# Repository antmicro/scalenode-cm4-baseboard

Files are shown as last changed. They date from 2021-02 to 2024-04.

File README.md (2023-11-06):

# Scalenode CM4 Baseboard

Copyright (c) 2020-2023 [Antmicro](https://www.antmicro.com)



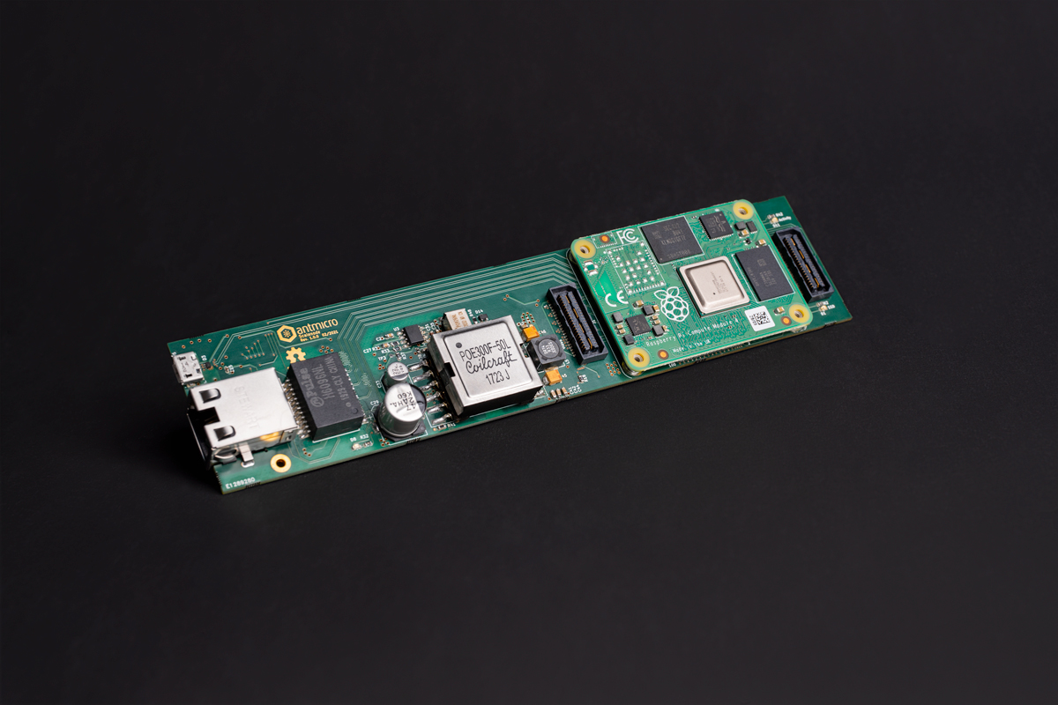
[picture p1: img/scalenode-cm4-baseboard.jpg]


## Overview

This project contains the PCB design files for a baseboard supporting System on Modules with pinout compatible with Raspberry Pi Compute Module 4 (CM4).
The baseboard has been optimized for 19-inch rack mount installations for distributed multi-node computing systems.

## Project structure

The main directory contains KiCad PCB project files, a [LICENSE](LICENSE), and a README.
The remaining files are stored in the following directories:

* `lib` - contains the KiCad component libraries
* `doc` - contains generated schematics and other documentation
* `img` - contains graphics for this README
* `assets` - contains visual assets for showcasing this design on [Open Hardware Portal](https://openhardware.antmicro.com)

## Key features

* Supports Raspberry Pi CM4
* Gigabit Ethernet with integrated PoE circuitry
* On-board M.2 (key-M) slot supporting NVMe SSDs 
* Slim PCB outline for 1U chassis
* Expansion connector for peripherals connected over USB
* Expansion connector for HDMI adapters

## Block diagram

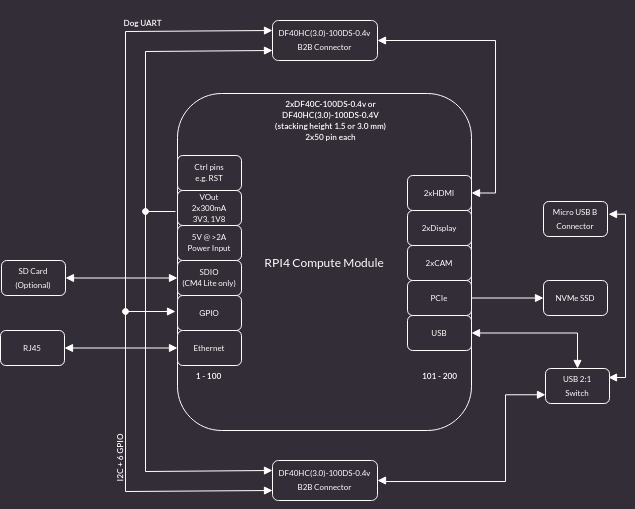
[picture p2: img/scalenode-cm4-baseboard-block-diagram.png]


## License

This project is published under the [Apache-2.0](LICENSE) license.

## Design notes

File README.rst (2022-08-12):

=======================
Scalenode CM4 Baseboard
=======================

Copyright (c) 2020-2021 `Antmicro <https://www.antmicro.com>`_



Overview
========

This repository contains the PCB design files for a baseboard supporting System on Modules with pinout compatible with Raspberry Pi Compute Module 4 (CM4).
The baseboard has been optimized for 19-inch rack mount installations for distributed multi-node computing systems.

Key features
============

* Supports Raspberry Pi CM4
* Gigabit Ethernet with integrated PoE circuitry
* On-board M.2 (key-M) slot supporting NVMe SSDs 
* Slim PCB outline for 1U chassis
* Expansion connector for peripherals connected over USB
* Expansion connector for HDMI adapters

Board layout and dimensions
===========================

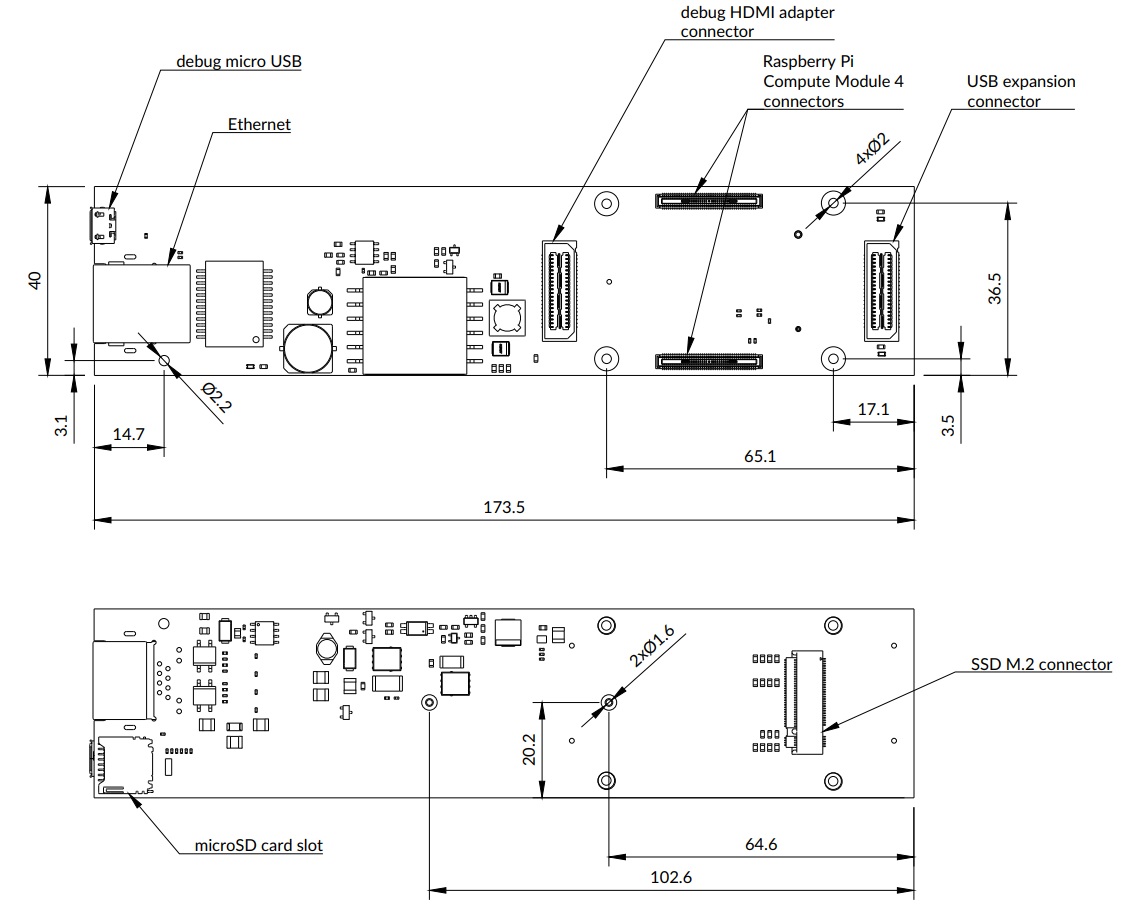
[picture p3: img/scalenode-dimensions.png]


License
=======

`Apache-2.0 <LICENSE>`_

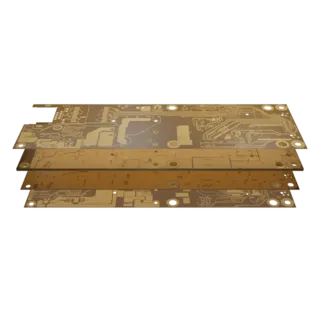
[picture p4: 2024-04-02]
assets/previews/layer1_thumbnail.webp

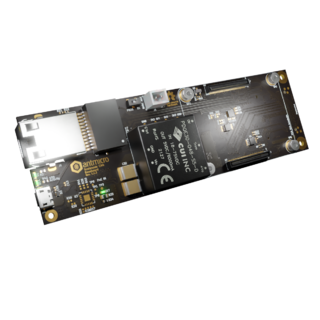
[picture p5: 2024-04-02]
assets/previews/leftT_thumbnail.png

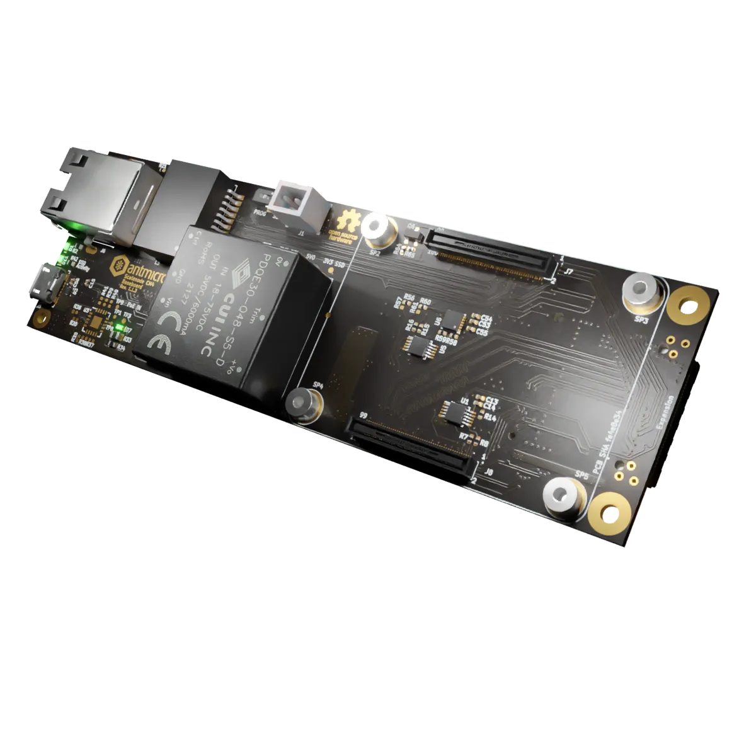
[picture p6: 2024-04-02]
assets/previews/rightT.webp

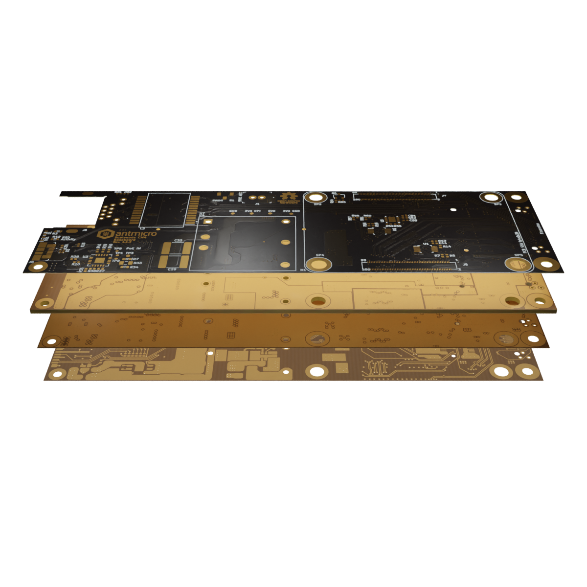
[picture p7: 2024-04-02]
assets/previews/stackup.png

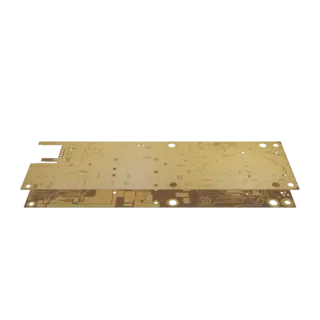
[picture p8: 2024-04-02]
assets/previews/layer3_thumbnail.webp

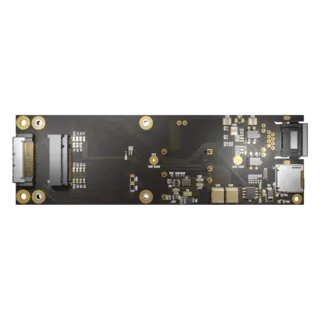
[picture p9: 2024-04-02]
assets/previews/orthoB_thumbnail.webp

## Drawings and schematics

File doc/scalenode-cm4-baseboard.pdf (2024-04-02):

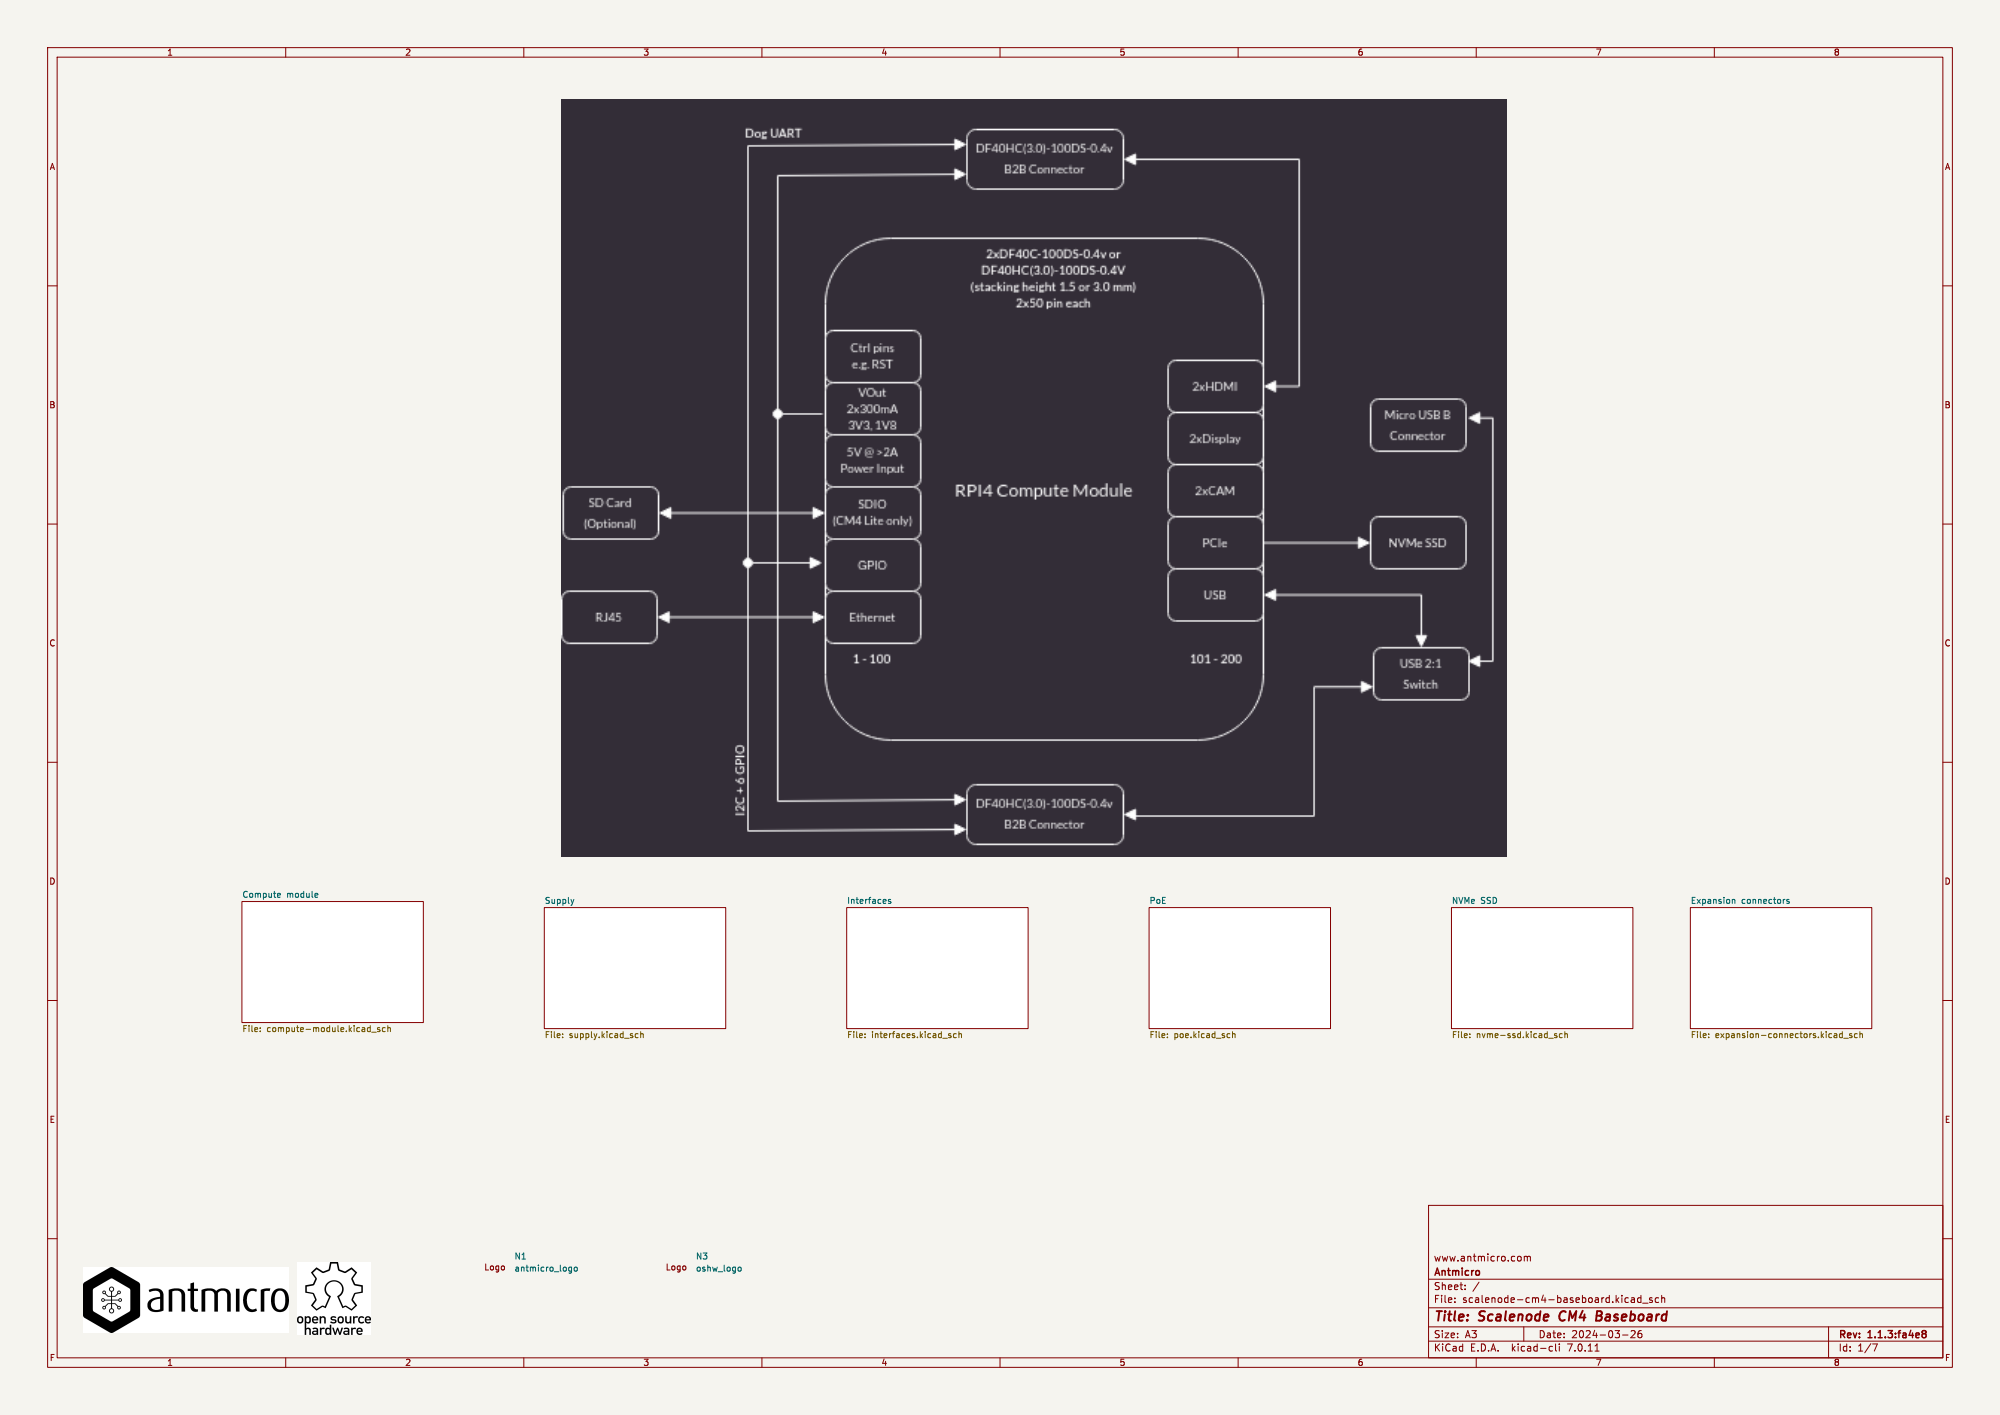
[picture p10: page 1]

File: scalenode-cm4-baseboard.kicad_sch Sheet: / Antmicro www.antmicro.com

Id: 1/7 Title: Scalenode CM4 Baseboard

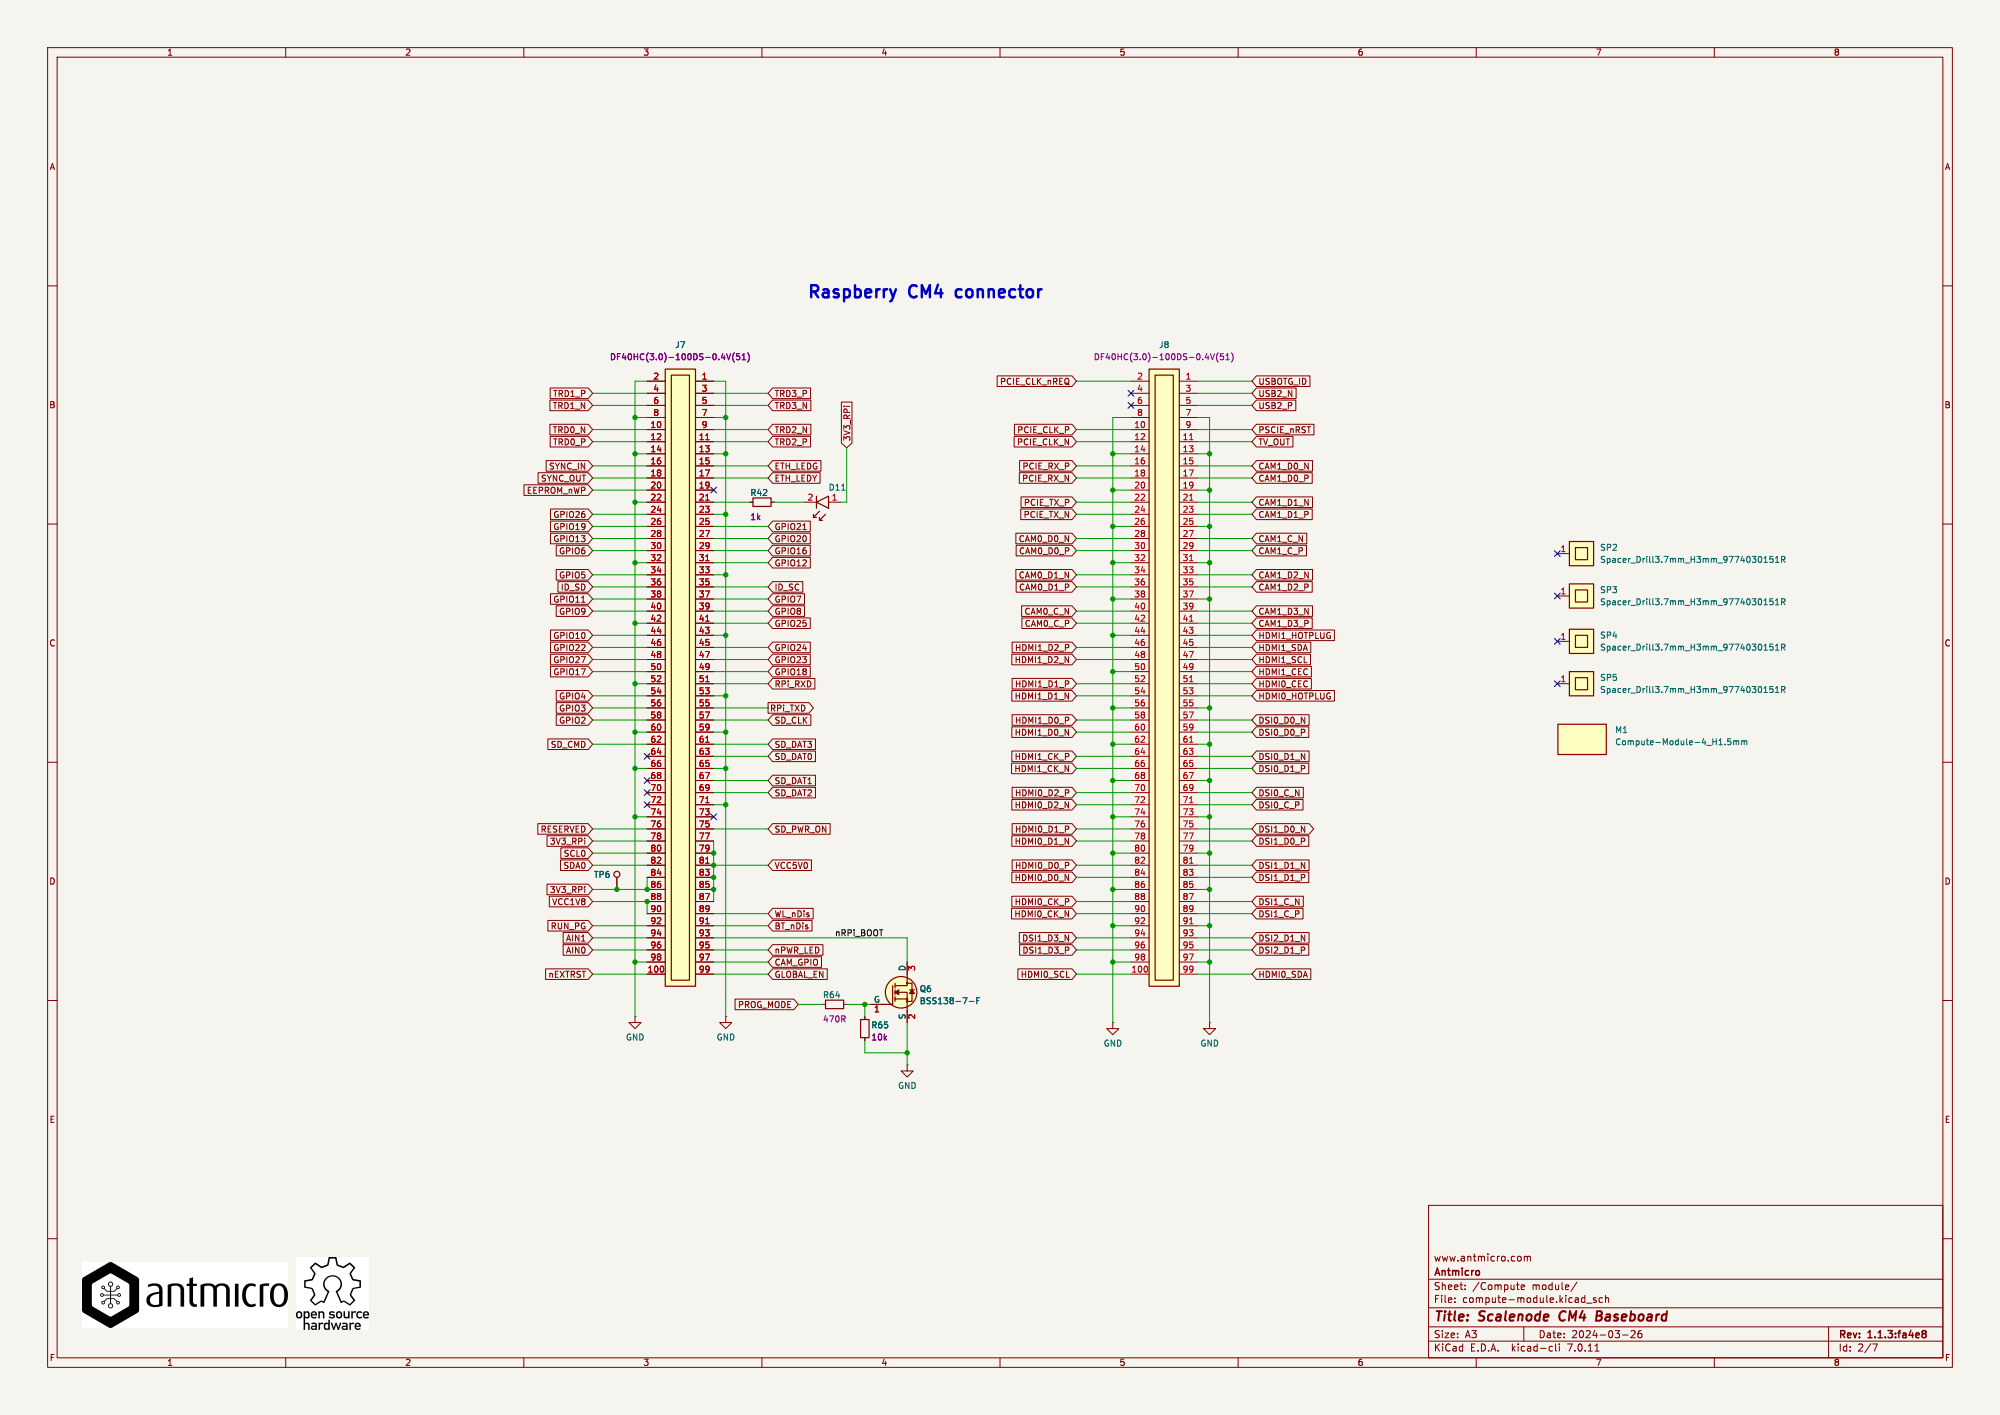
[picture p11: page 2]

Id: 2/7 Title: Scalenode CM4 Baseboard

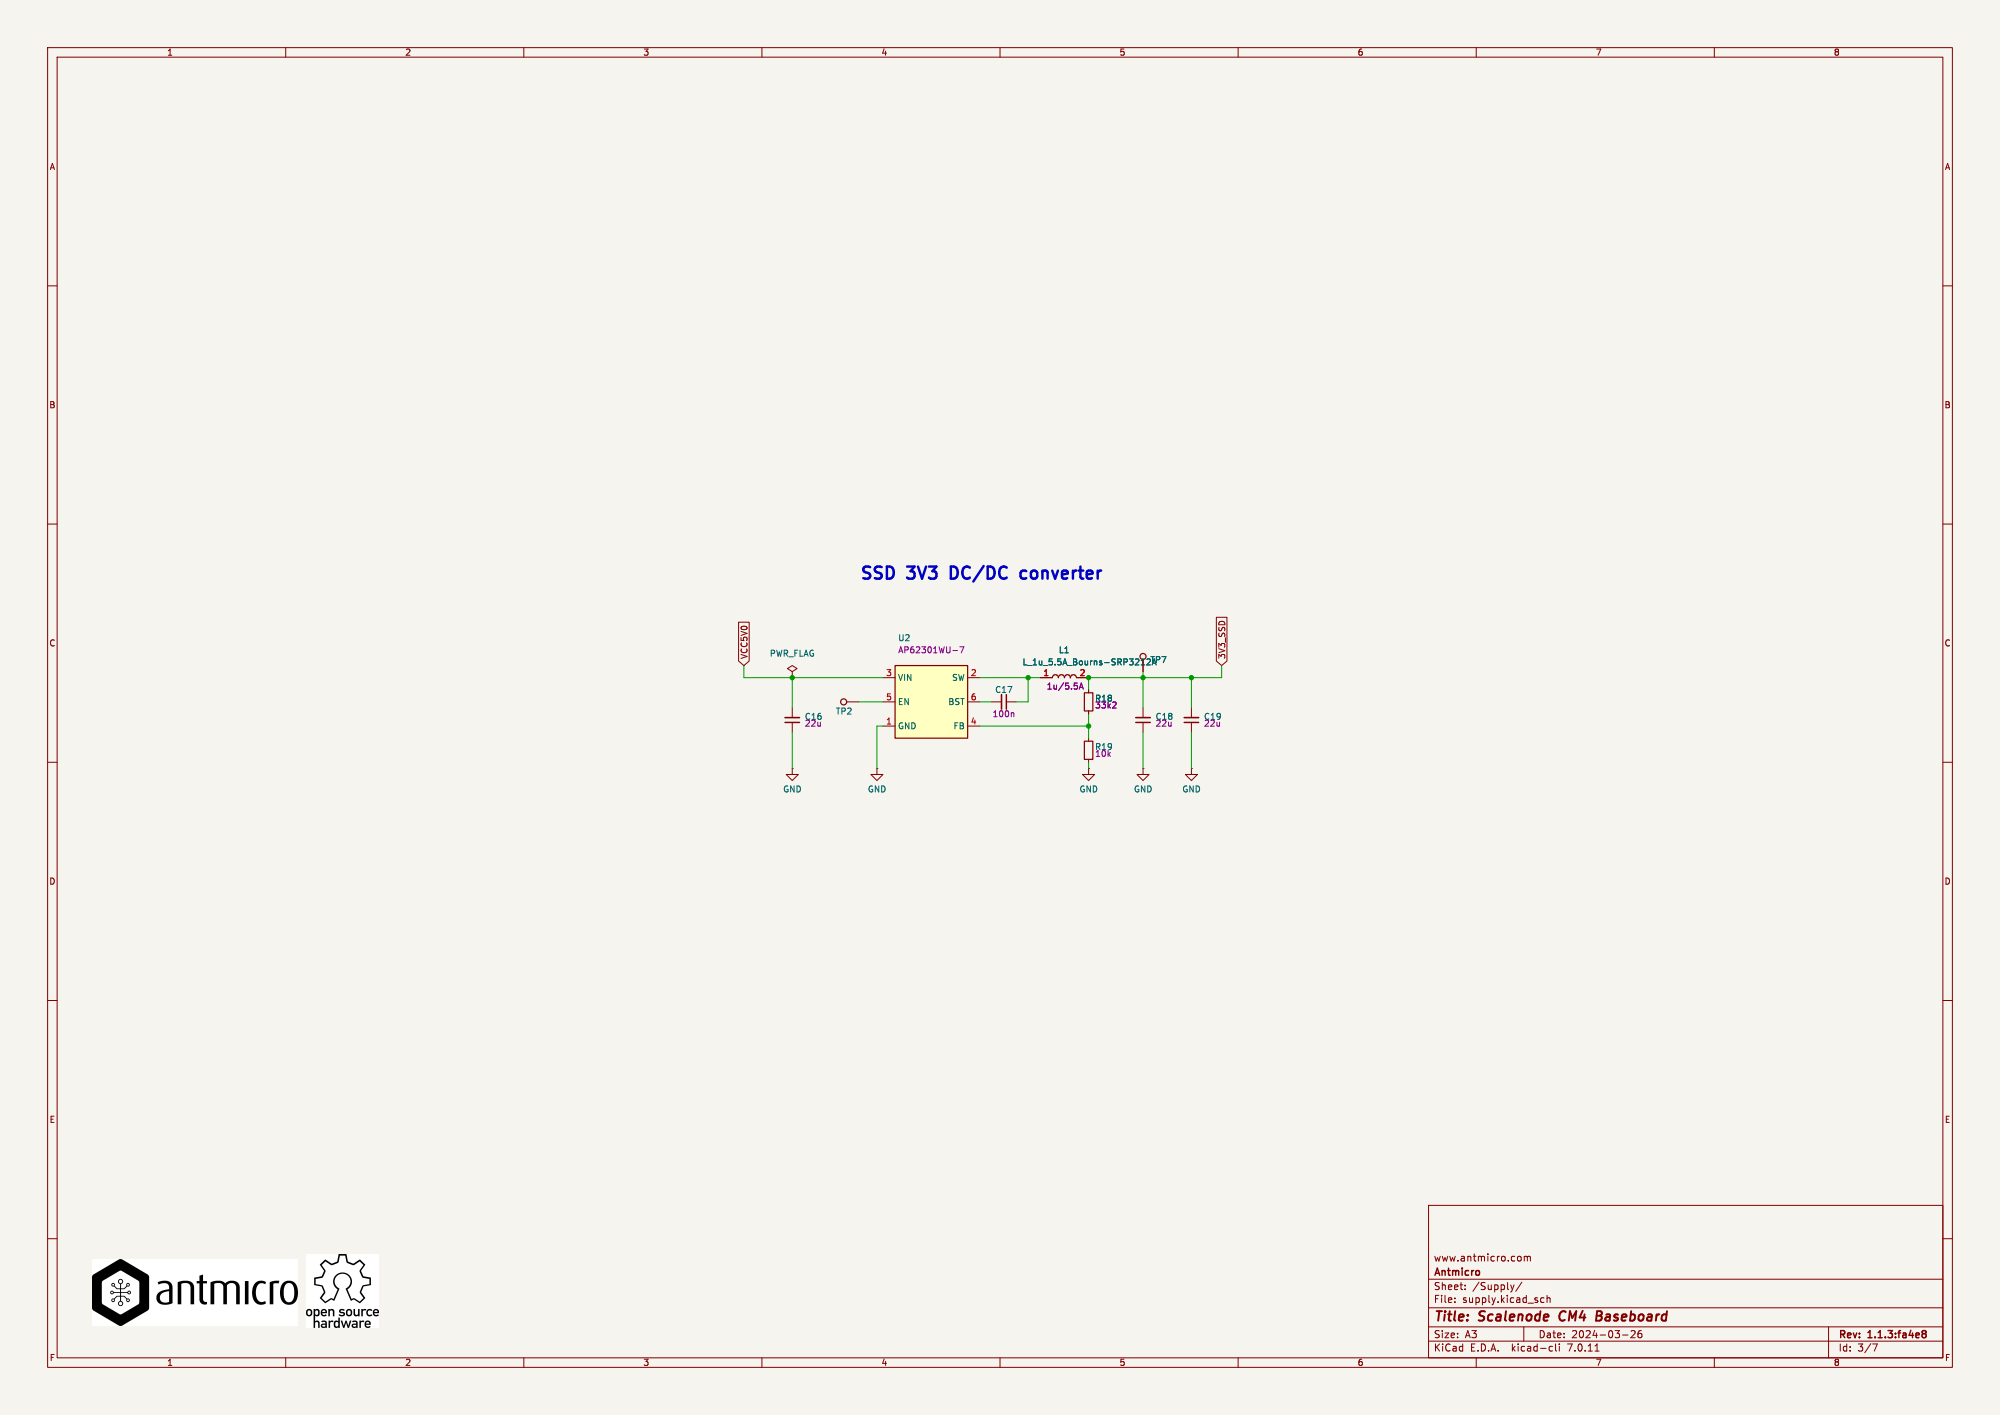
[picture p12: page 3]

File: supply.kicad_sch Sheet: /Supply/ Antmicro www.antmicro.com

Id: 3/7 Title: Scalenode CM4 Baseboard

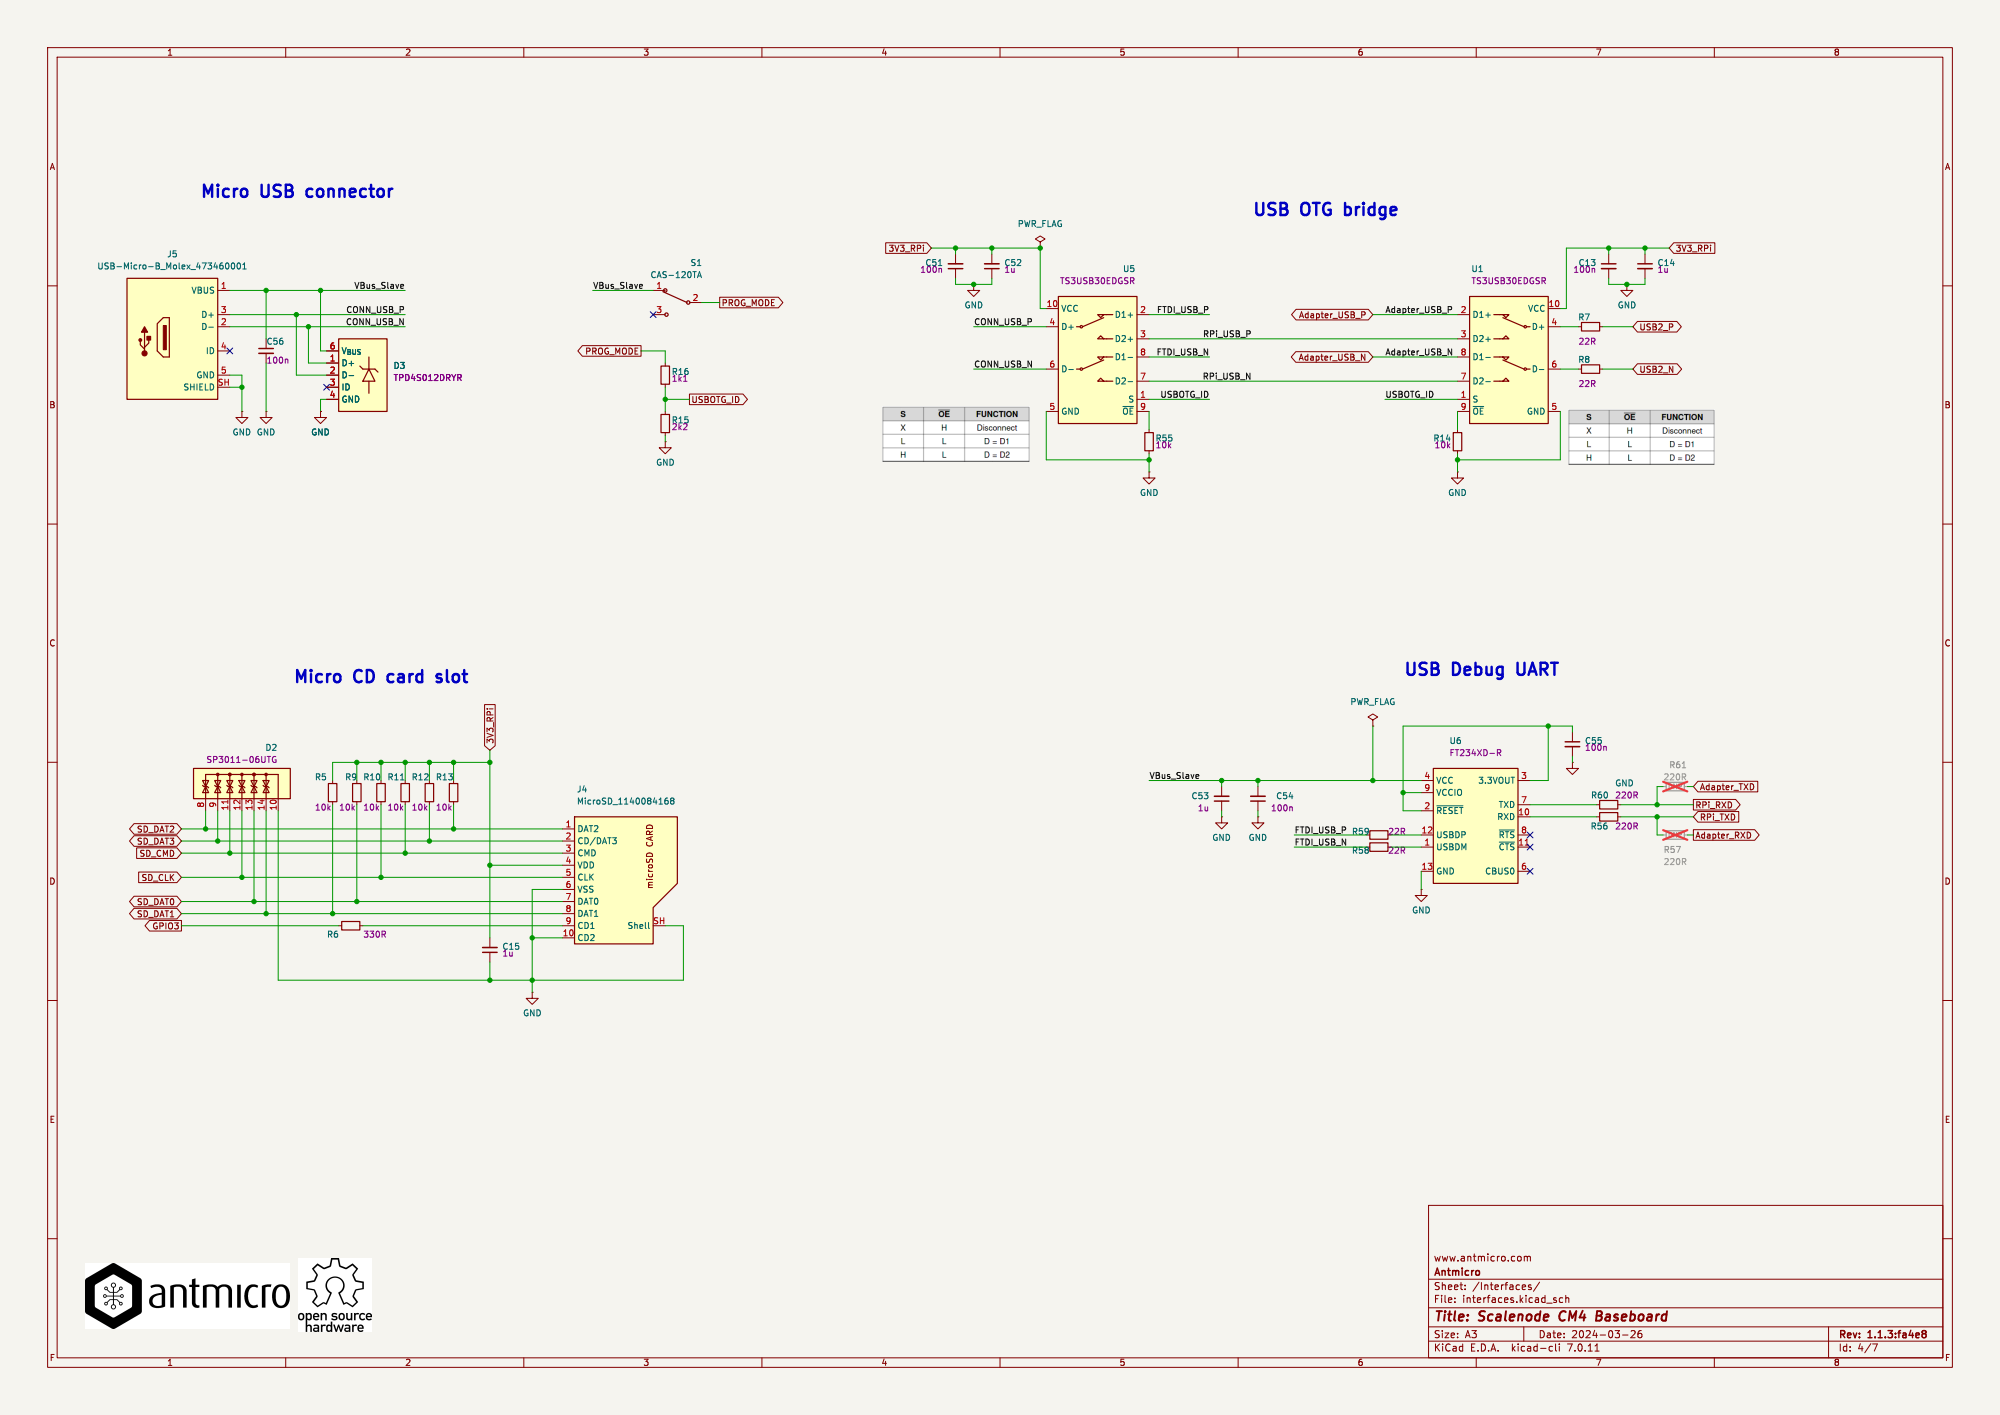
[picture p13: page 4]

ID 4 GND 5 SHIELD SH

ID 3 GND 4 V_{BUS} 6 GND

USB Debug UART Micro CD card slot

File: interfaces.kicad_sch Sheet: /Interfaces/ Antmicro www.antmicro.com

Id: 4/7 Title: Scalenode CM4 Baseboard

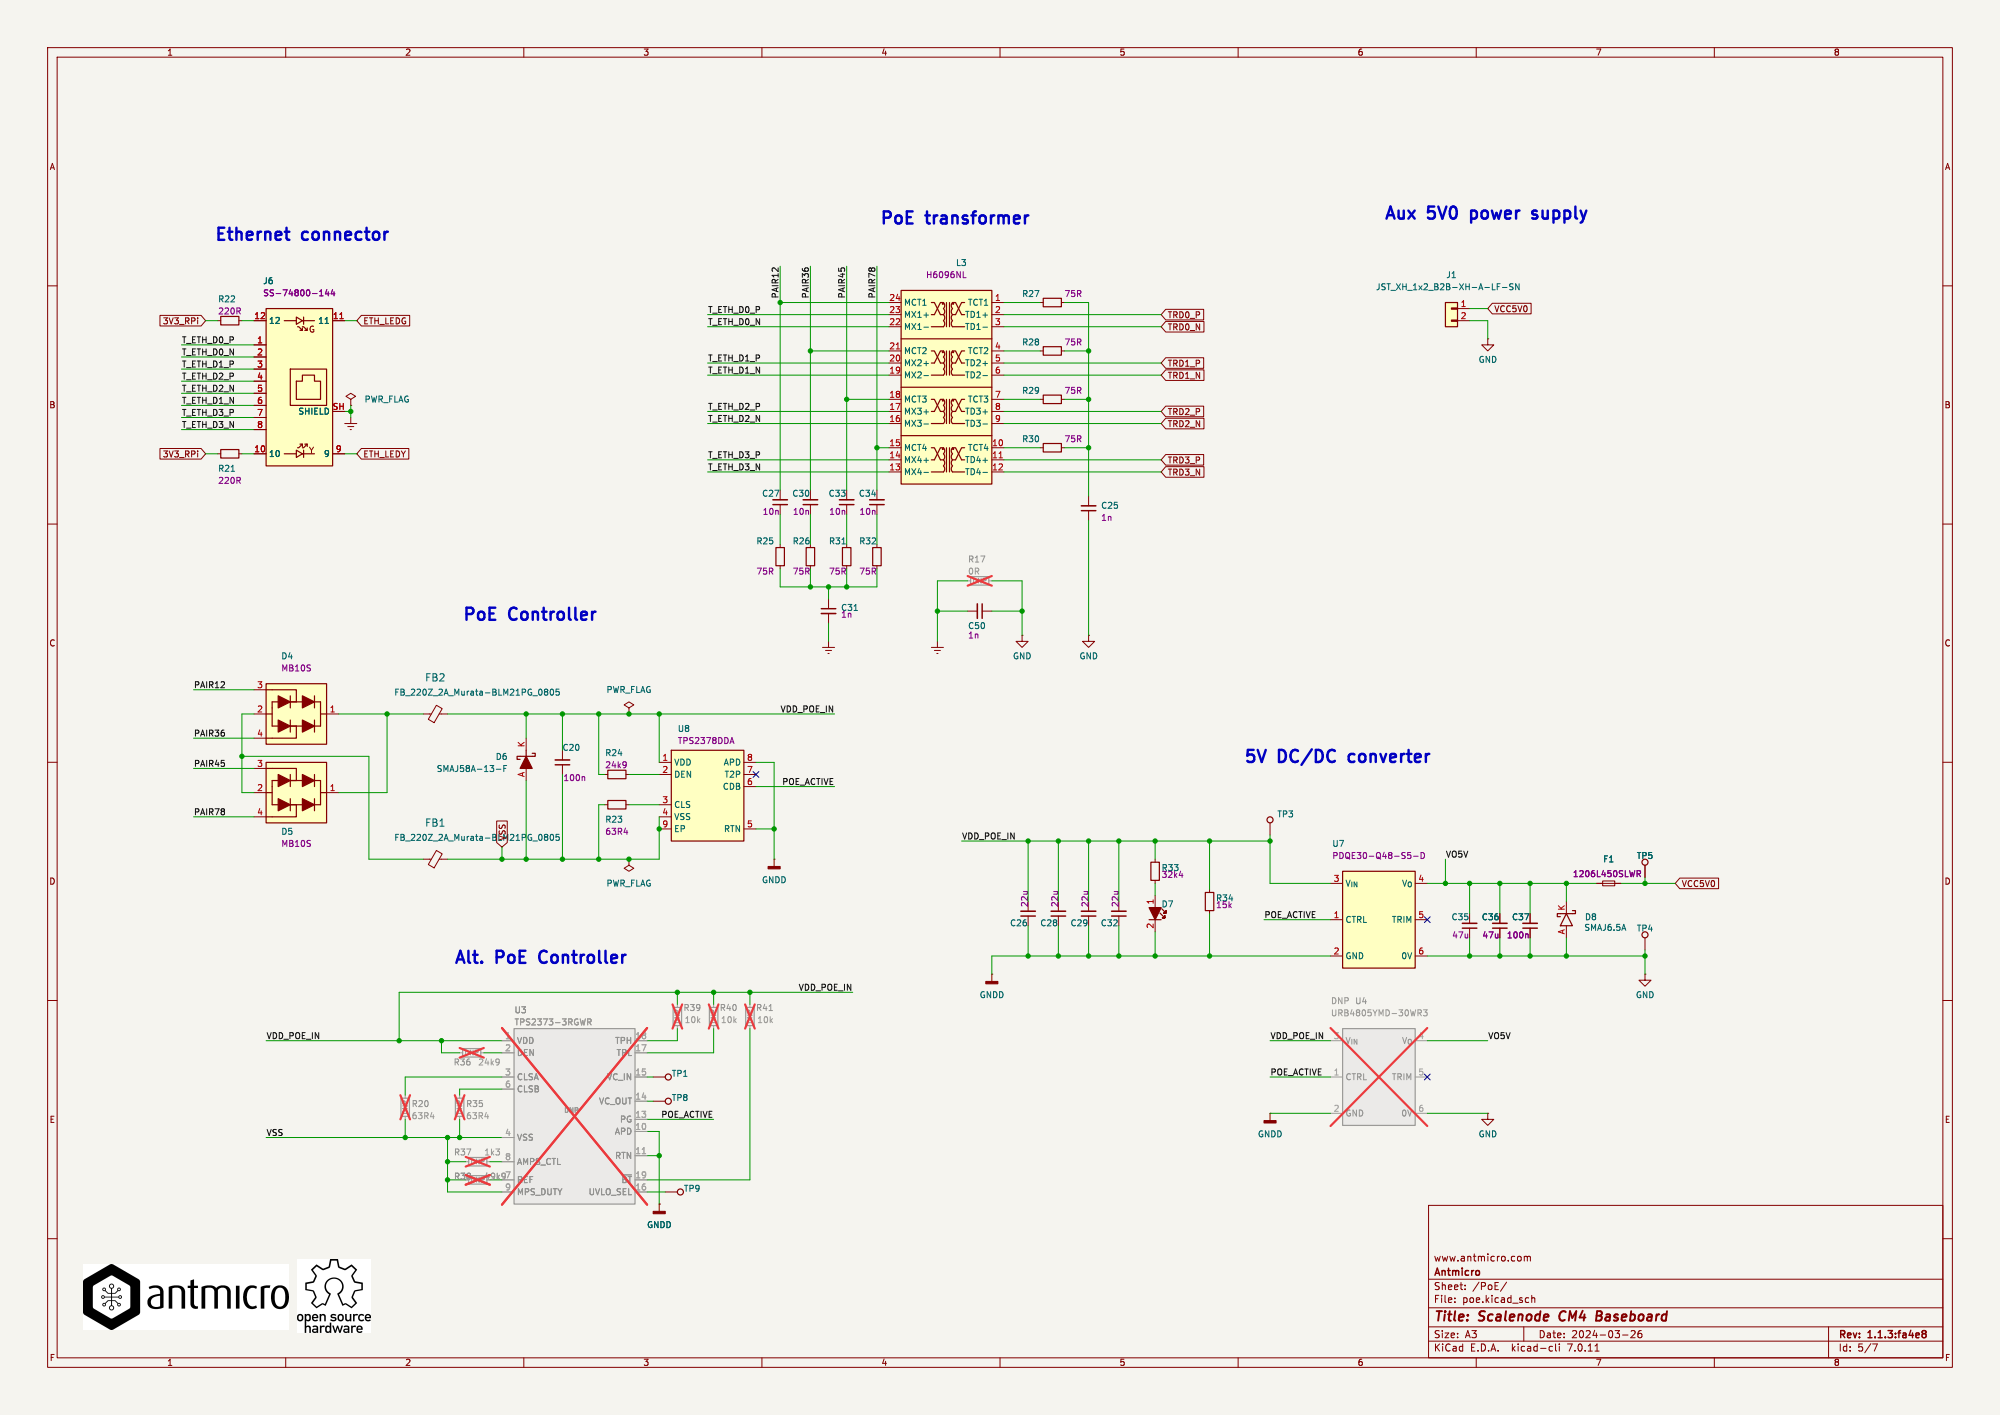
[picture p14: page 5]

Id: 5/7 Title: Scalenode CM4 Baseboard

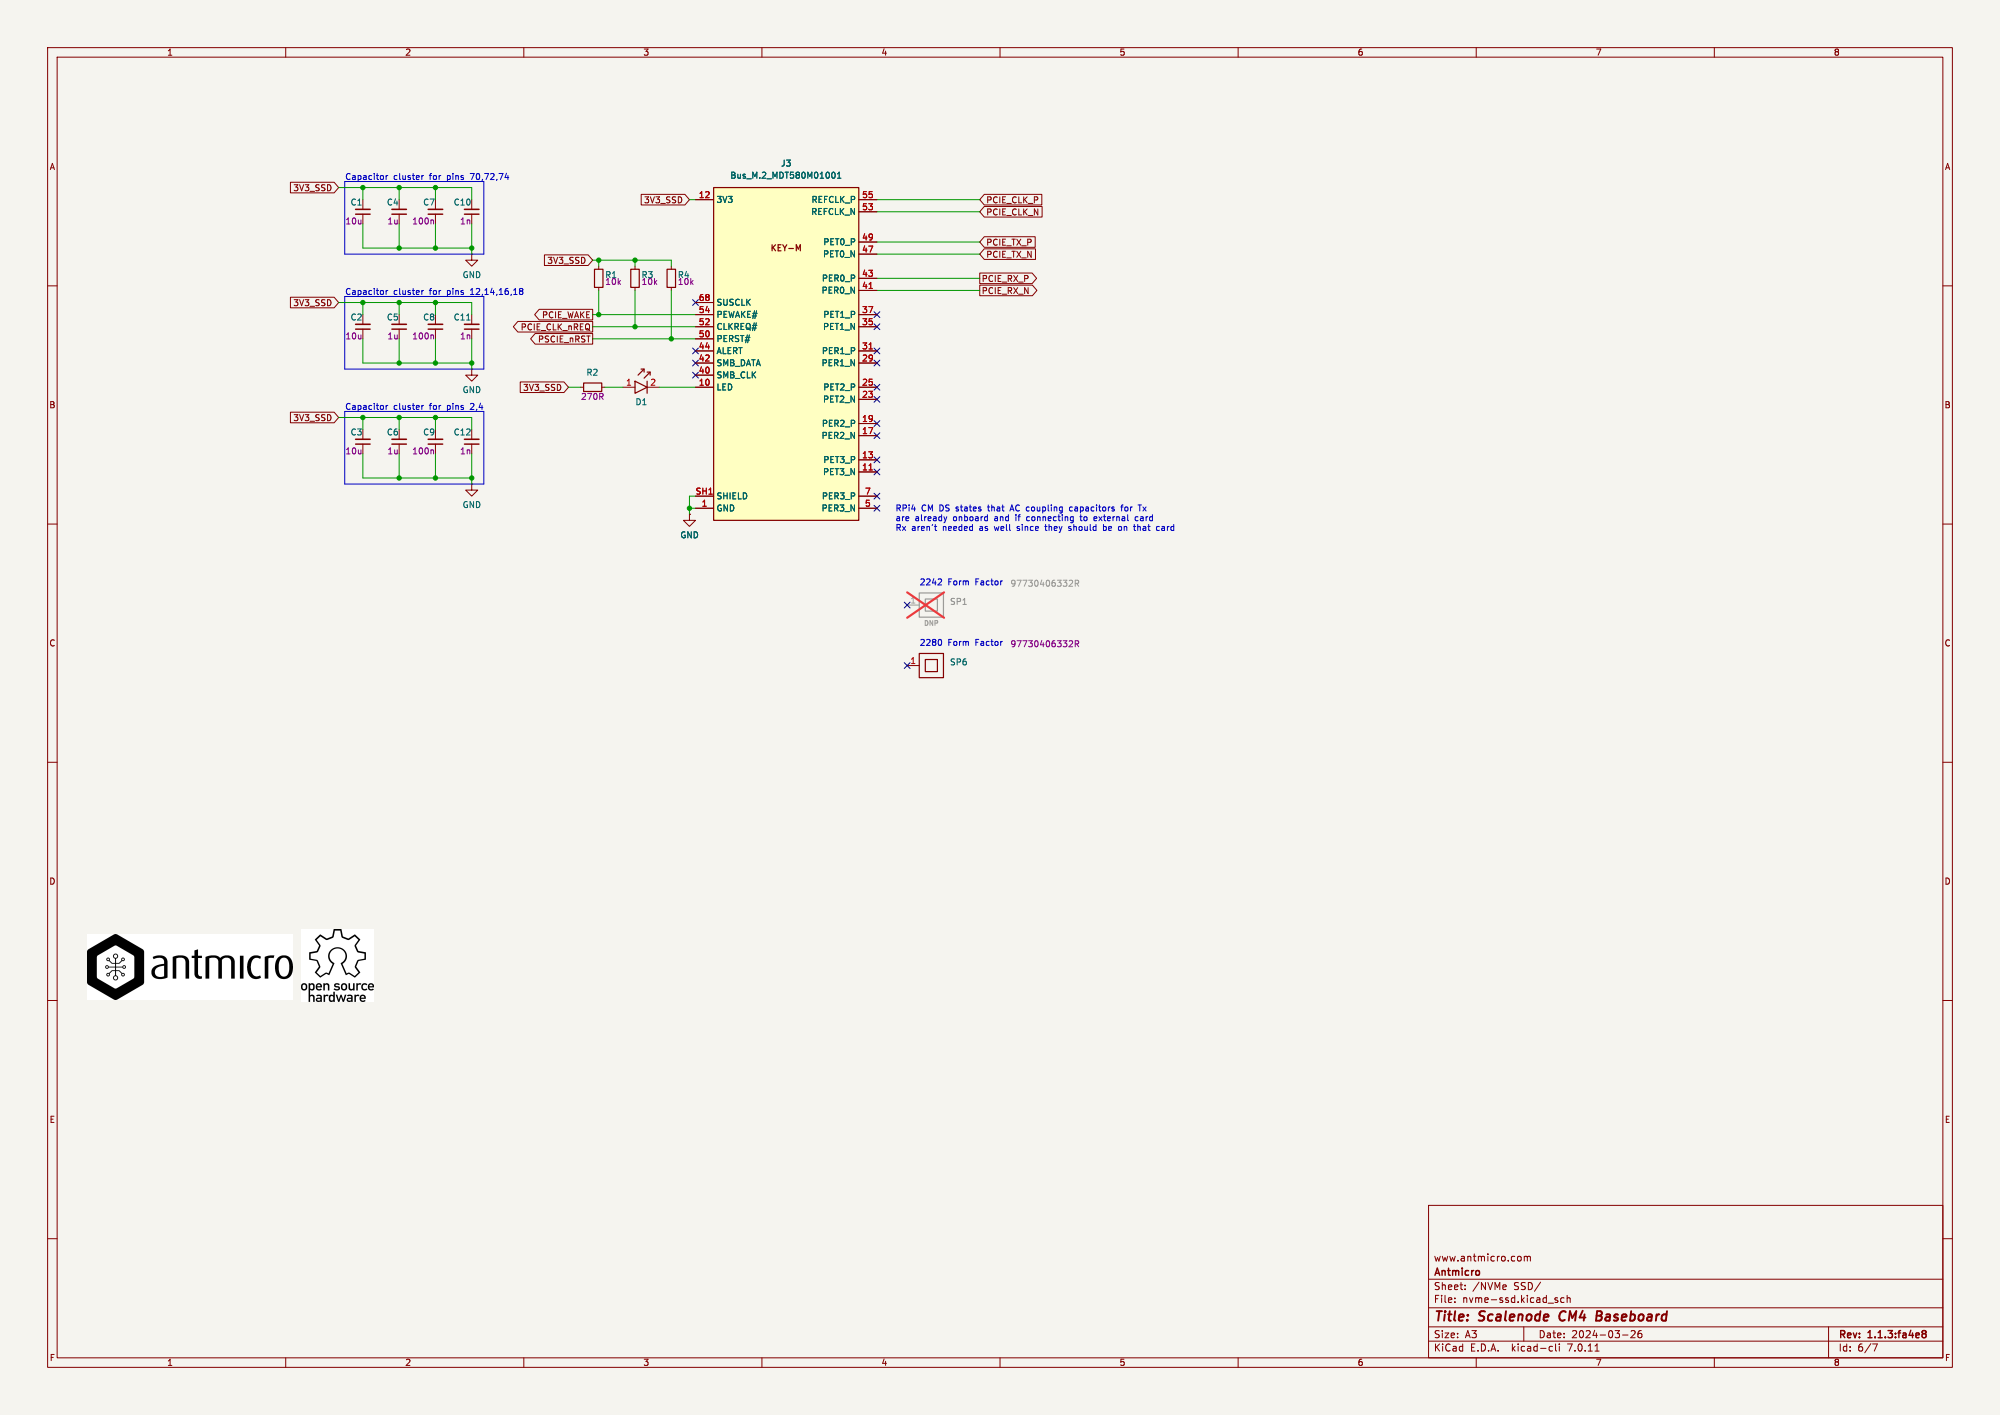
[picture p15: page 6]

File: nvme-ssd.kicad_sch Sheet: /NVMe SSD/ Antmicro www.antmicro.com

Id: 6/7 Title: Scalenode CM4 Baseboard

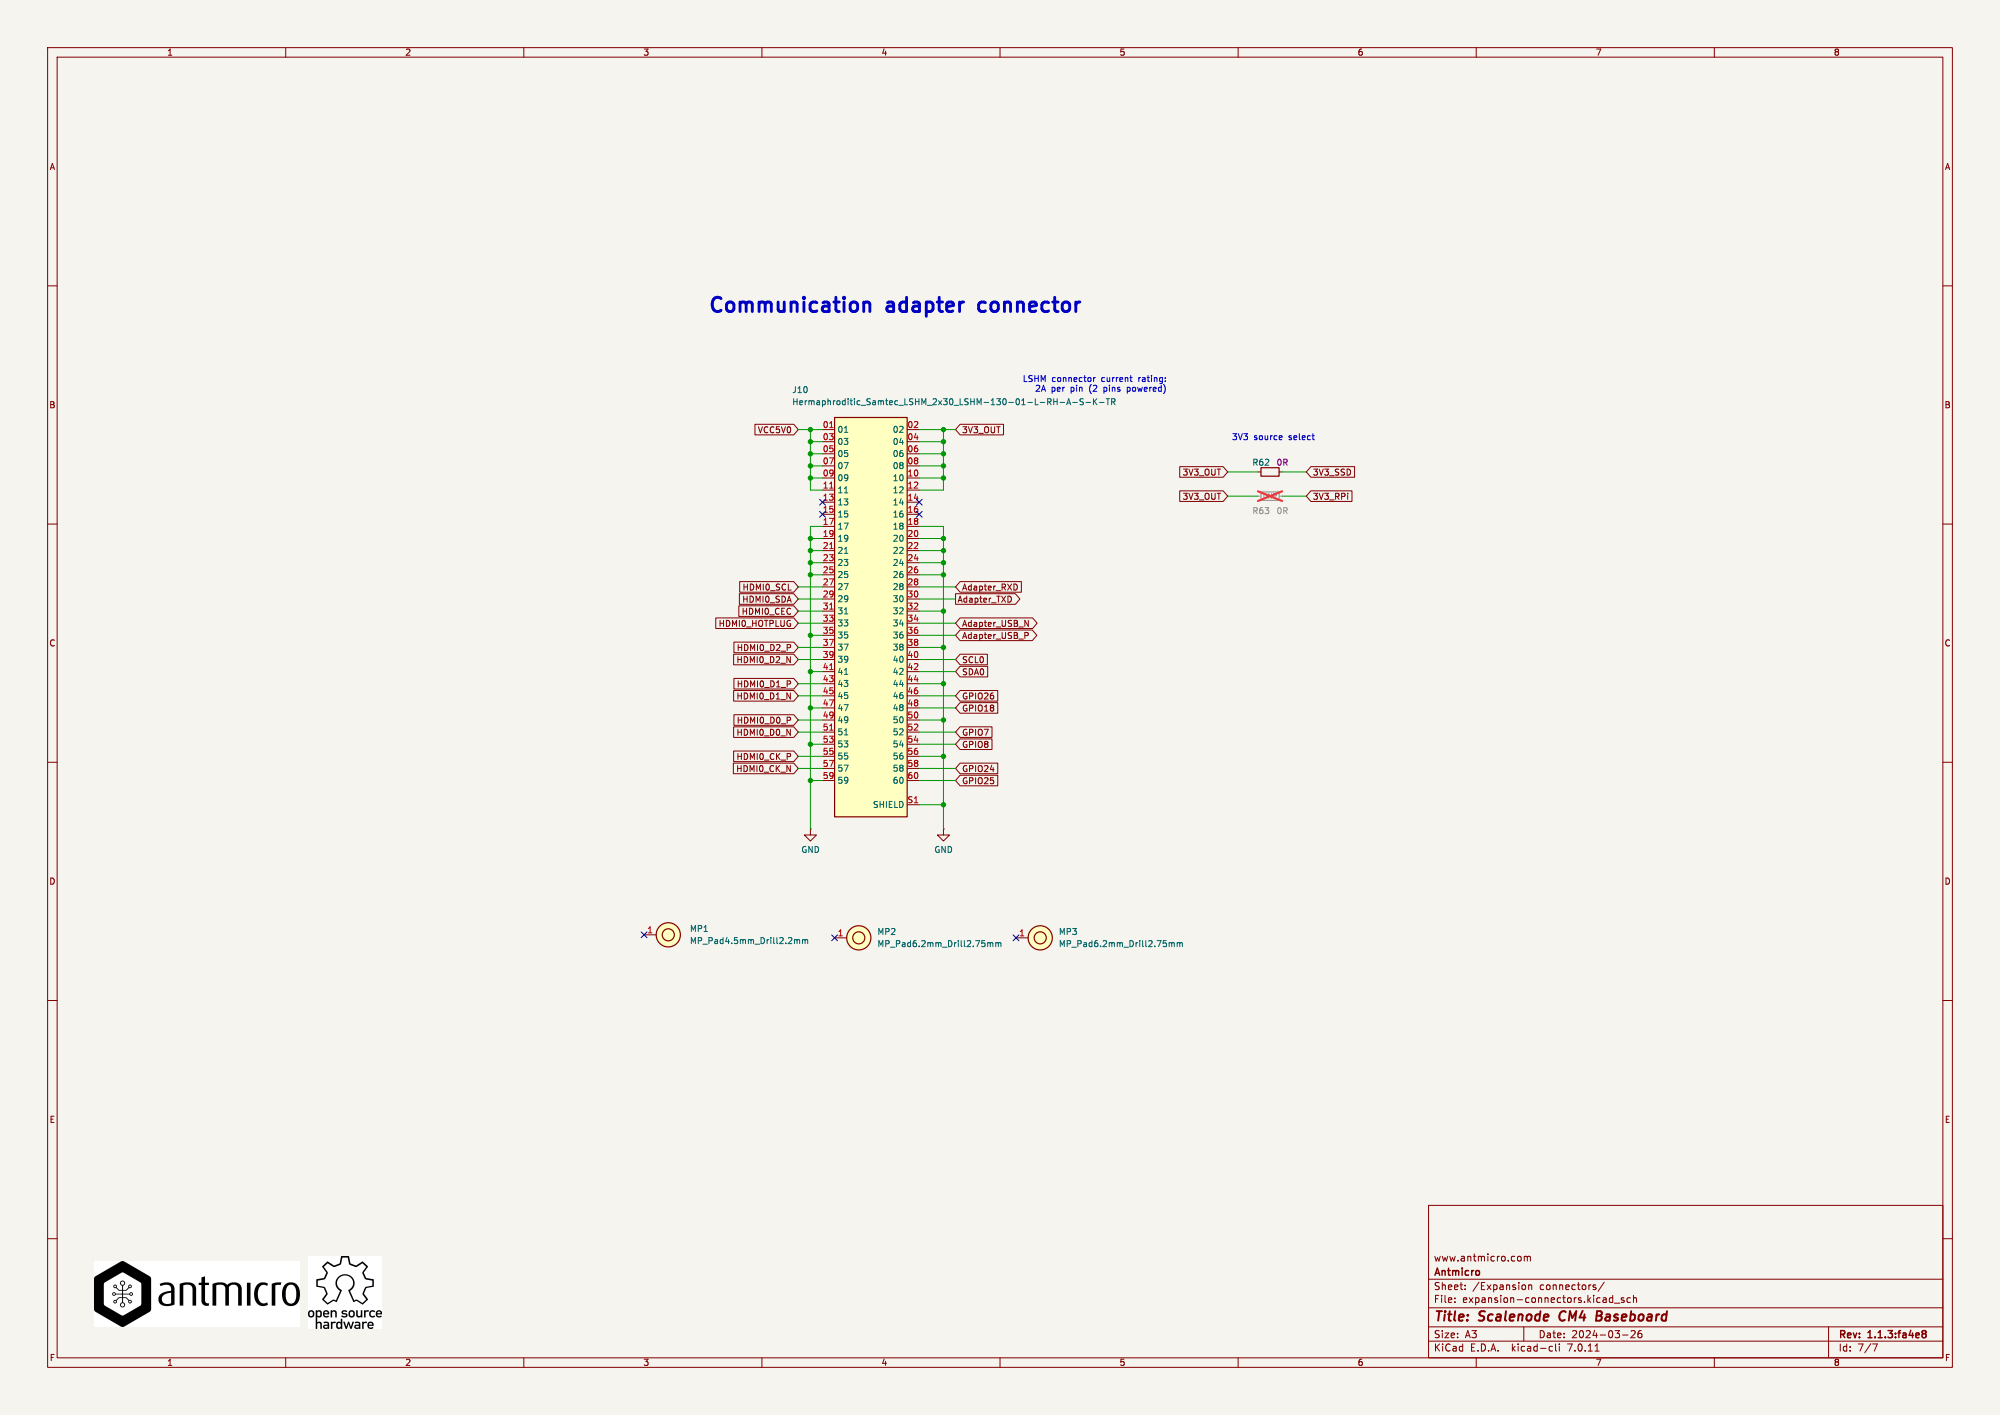
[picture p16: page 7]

Id: 7/7 Title: Scalenode CM4 Baseboard

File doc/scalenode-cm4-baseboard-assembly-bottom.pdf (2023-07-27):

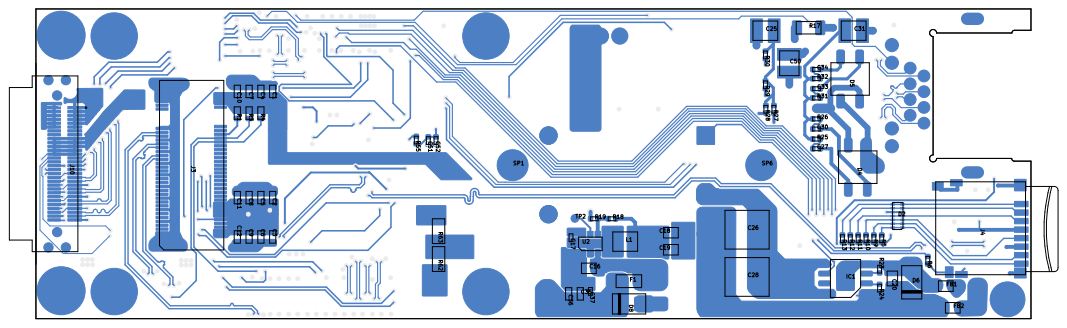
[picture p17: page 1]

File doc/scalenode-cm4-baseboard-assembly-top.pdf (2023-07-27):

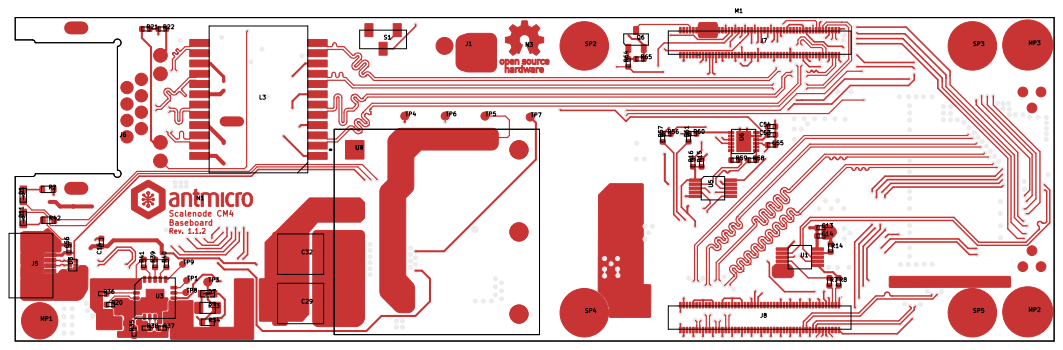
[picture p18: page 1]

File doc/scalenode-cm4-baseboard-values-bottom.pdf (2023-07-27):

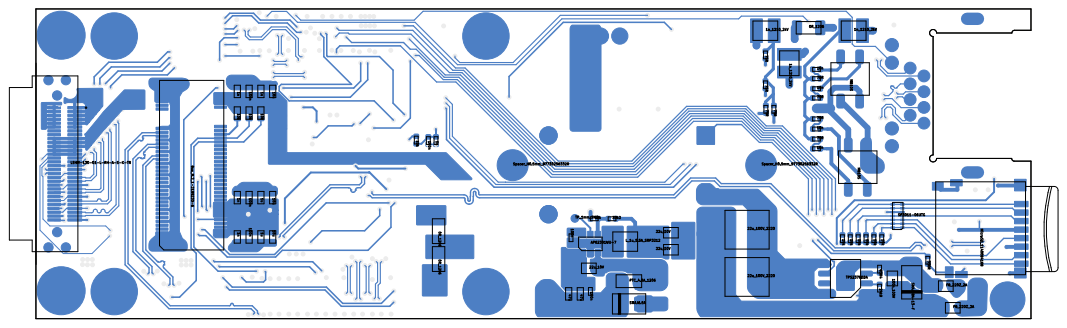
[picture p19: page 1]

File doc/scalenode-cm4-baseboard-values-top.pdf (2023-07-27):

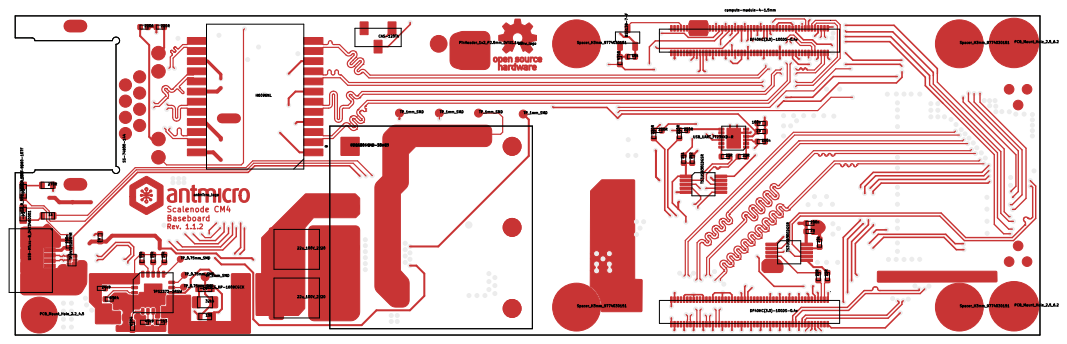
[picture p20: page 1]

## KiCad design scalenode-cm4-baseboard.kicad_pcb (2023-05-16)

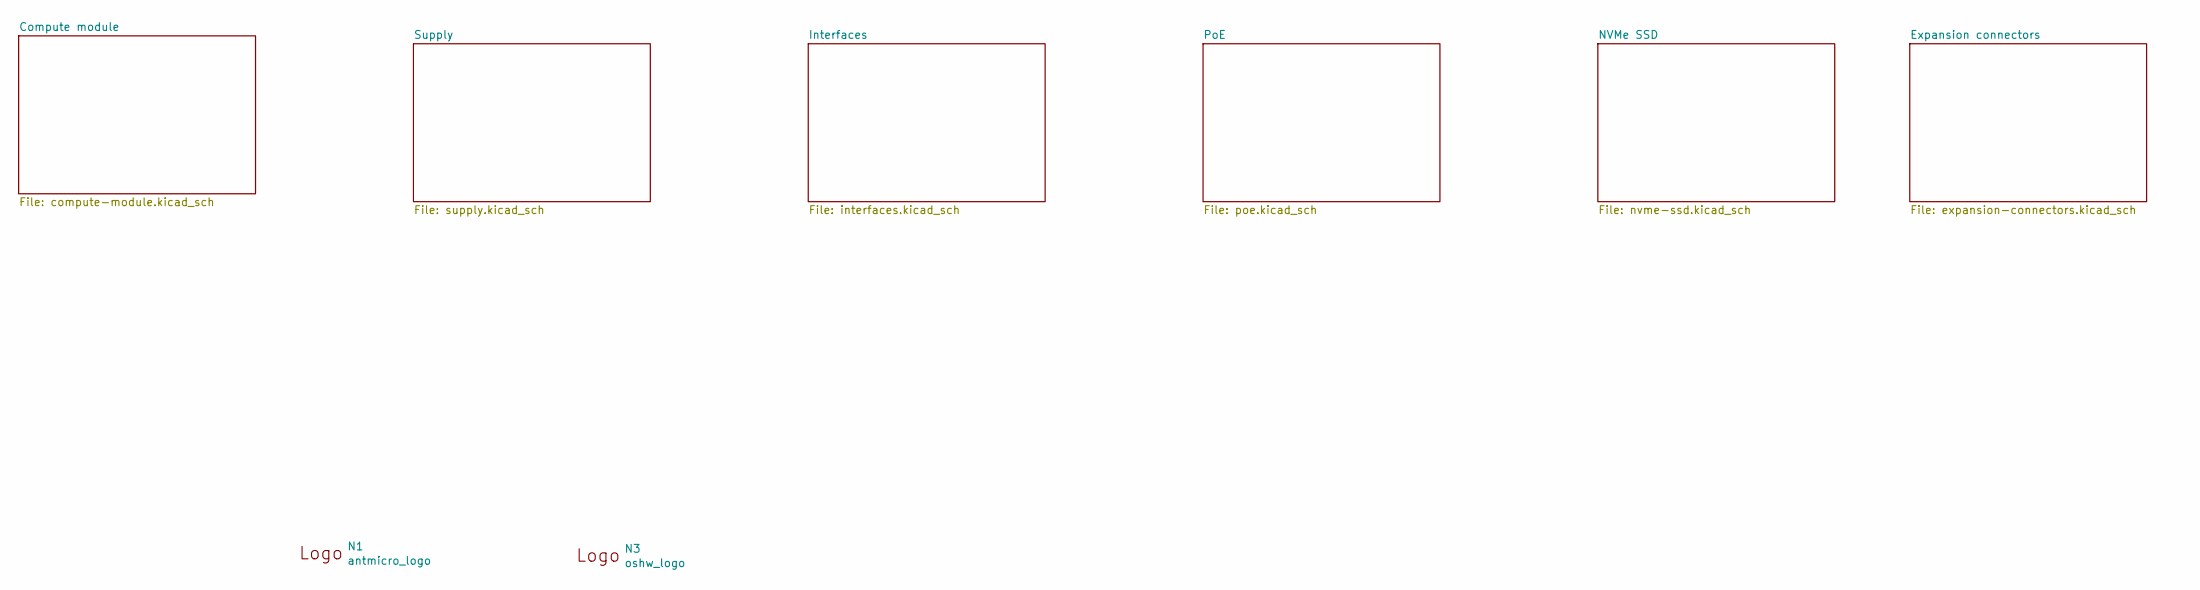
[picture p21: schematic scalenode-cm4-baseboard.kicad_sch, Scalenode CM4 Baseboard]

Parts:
N1: antmicro_logo; antmicro-logo_scaled_15mm
N3: oshw_logo; oshw-logo

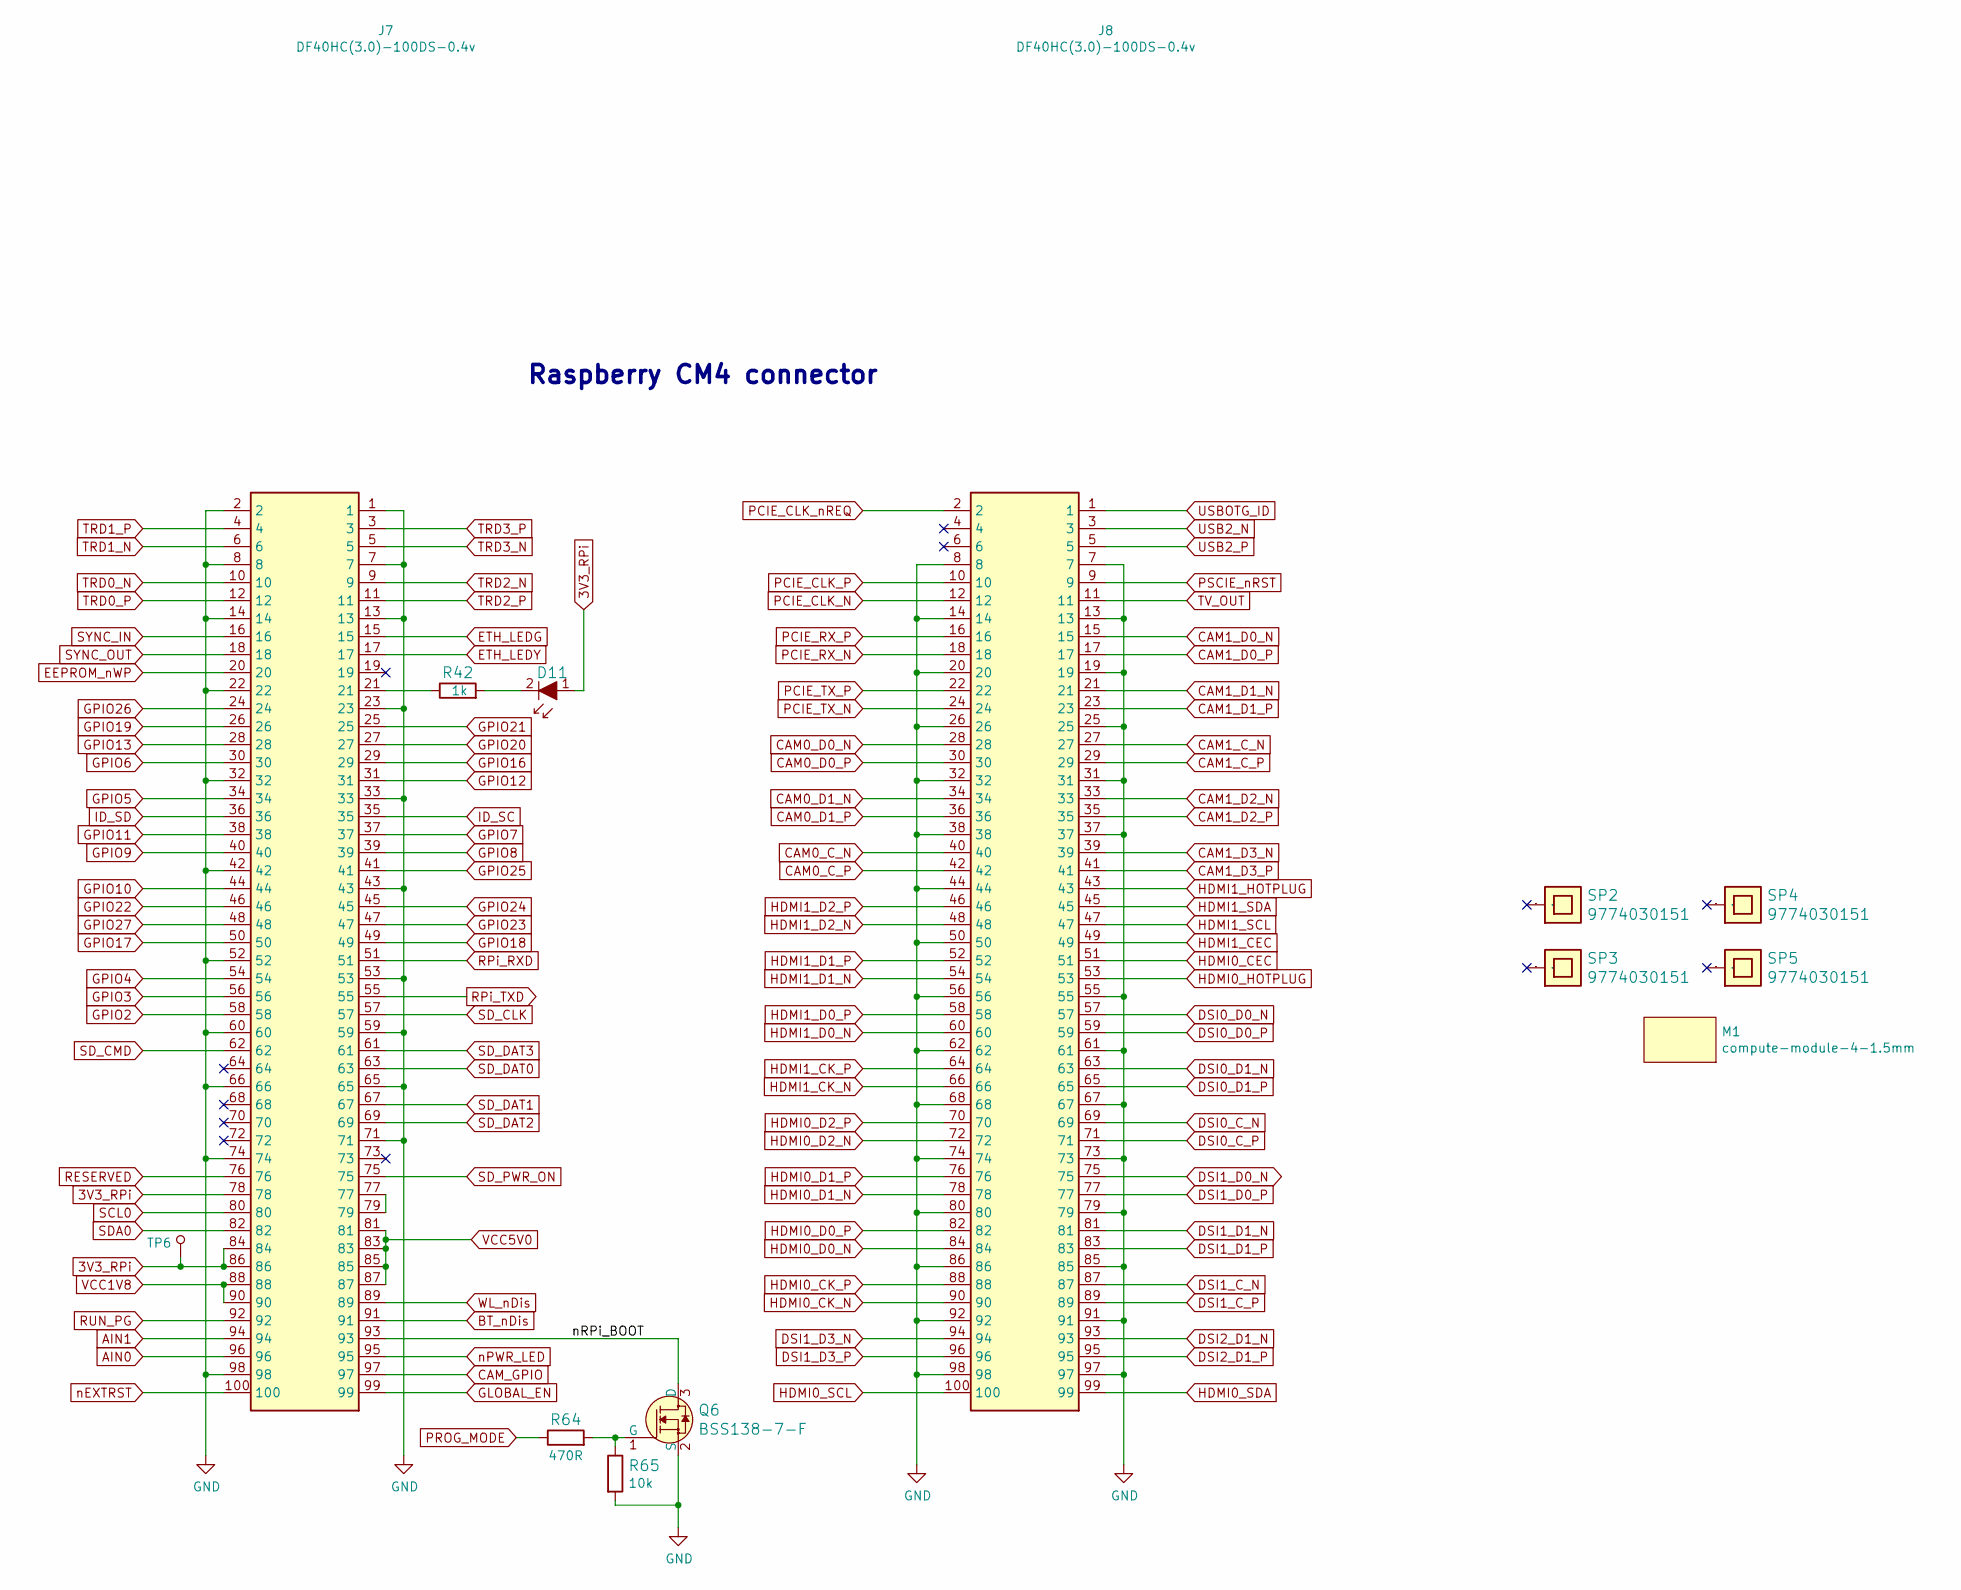
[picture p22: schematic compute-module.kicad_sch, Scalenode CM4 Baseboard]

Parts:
D11: 598-8D80-107F; LED_0603_R; MPN 598-8D80-107F
J7, J8: DF40HC(3.0)-100DS-0.4v; MPN DF40HC(3.0)-100DS-0.4v(51
M1: compute-module-4-1.5mm
Q6: BSS138-7-F; SOT-23-3; MPN BSS138-7-F
R42: R_1k_0603; 0603-res; MPN CR0603-JW-102ELF
R64: R_470R_0402; 0402-res; MPN CRCW0402470RFKED
R65: R_10k_0402; 0402-res; MPN CRCW040210K0FKEDHP
SP2, SP3, SP4, SP5: 9774030151; MPN 9774030151
TP6: TP_SMD1MM; Testpoint_smd_1mm

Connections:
3V3_RPi: D11.1, J7.78, J7.84, J7.86, TP6.1; also elsewhere on the board
/Compute module/nRPi_BOOT: J7.93, Q6.3 (D)
AIN0: J7.96
AIN1: J7.94
BT_nDis: J7.91
CAM0_C_N: J8.40
CAM0_C_P: J8.42
CAM0_D0_N: J8.28
CAM0_D0_P: J8.30
CAM0_D1_N: J8.34
CAM0_D1_P: J8.36
CAM1_C_N: J8.27
CAM1_C_P: J8.29
CAM1_D0_N: J8.15
CAM1_D0_P: J8.17
CAM1_D1_N: J8.21
CAM1_D1_P: J8.23
CAM1_D2_N: J8.33
CAM1_D2_P: J8.35
CAM1_D3_N: J8.39
CAM1_D3_P: J8.41
CAM_GPIO: J7.97
DSI0_C_N: J8.69
DSI0_C_P: J8.71
DSI0_D0_N: J8.57
DSI0_D0_P: J8.59
DSI0_D1_N: J8.63
DSI0_D1_P: J8.65
DSI1_C_N: J8.87
DSI1_C_P: J8.89
DSI1_D0_N: J8.75
DSI1_D0_P: J8.77
DSI1_D1_N: J8.81
DSI1_D1_P: J8.83
DSI1_D3_N: J8.94
DSI1_D3_P: J8.96
DSI2_D1_N: J8.93
DSI2_D1_P: J8.95
EEPROM_nWP: J7.20
ETH_LEDG: J7.15; also elsewhere on the board
ETH_LEDY: J7.17; also elsewhere on the board
GLOBAL_EN: J7.99
GPIO2: J7.58
GPIO3: J7.56; also elsewhere on the board
GPIO4: J7.54
GPIO5: J7.34
GPIO6: J7.30
GPIO7: J7.37; also elsewhere on the board
GPIO8: J7.39; also elsewhere on the board
GPIO9: J7.40
GPIO10: J7.44
GPIO11: J7.38
GPIO12: J7.31
GPIO13: J7.28
GPIO16: J7.29
GPIO17: J7.50
GPIO18: J7.49; also elsewhere on the board
GPIO19: J7.26
GPIO20: J7.27
GPIO21: J7.25
GPIO22: J7.46
GPIO23: J7.47
GPIO24: J7.45; also elsewhere on the board
GPIO25: J7.41; also elsewhere on the board
GPIO26: J7.24; also elsewhere on the board
GPIO27: J7.48
HDMI0_CEC: J8.51; also elsewhere on the board
HDMI0_CK_N: J8.90; also elsewhere on the board
HDMI0_CK_P: J8.88; also elsewhere on the board
HDMI0_D0_N: J8.84; also elsewhere on the board
HDMI0_D0_P: J8.82; also elsewhere on the board
HDMI0_D1_N: J8.78; also elsewhere on the board
HDMI0_D1_P: J8.76; also elsewhere on the board
HDMI0_D2_N: J8.72; also elsewhere on the board
HDMI0_D2_P: J8.70; also elsewhere on the board
HDMI0_HOTPLUG: J8.53; also elsewhere on the board
HDMI0_SCL: J8.100; also elsewhere on the board
HDMI0_SDA: J8.99; also elsewhere on the board
HDMI1_CEC: J8.49
HDMI1_CK_N: J8.66
HDMI1_CK_P: J8.64
HDMI1_D0_N: J8.60
HDMI1_D0_P: J8.58
HDMI1_D1_N: J8.54
HDMI1_D1_P: J8.52
HDMI1_D2_N: J8.48
HDMI1_D2_P: J8.46
HDMI1_HOTPLUG: J8.43
HDMI1_SCL: J8.47
HDMI1_SDA: J8.45
ID_SC: J7.35
ID_SD: J7.36
unnamed: D11.2, R42.2
unnamed: J7.21, R42.1
unnamed: Q6.1 (G), R64.2, R65.1
PCIE_CLK_N: J8.12; also elsewhere on the board
PCIE_CLK_P: J8.10; also elsewhere on the board
PCIE_CLK_nREQ: J8.2; also elsewhere on the board
PCIE_RX_N: J8.18; also elsewhere on the board
PCIE_RX_P: J8.16; also elsewhere on the board
PCIE_TX_N: J8.24; also elsewhere on the board
PCIE_TX_P: J8.22; also elsewhere on the board
PROG_MODE: R64.1; also elsewhere on the board
PSCIE_nRST: J8.9; also elsewhere on the board
RESERVED: J7.76
RPi_RXD: J7.51; also elsewhere on the board
RPi_TXD: J7.55; also elsewhere on the board
RUN_PG: J7.92
SCL0: J7.80; also elsewhere on the board
SDA0: J7.82; also elsewhere on the board
SD_CLK: J7.57; also elsewhere on the board
SD_CMD: J7.62; also elsewhere on the board
SD_DAT0: J7.63; also elsewhere on the board
SD_DAT1: J7.67; also elsewhere on the board
SD_DAT2: J7.69; also elsewhere on the board
SD_DAT3: J7.61; also elsewhere on the board
SD_PWR_ON: J7.75
SYNC_IN: J7.16
SYNC_OUT: J7.18
TRD0_N: J7.10; also elsewhere on the board
TRD0_P: J7.12; also elsewhere on the board
TRD1_N: J7.6; also elsewhere on the board
TRD1_P: J7.4; also elsewhere on the board
TRD2_N: J7.9; also elsewhere on the board
TRD2_P: J7.11; also elsewhere on the board
TRD3_N: J7.5; also elsewhere on the board
TRD3_P: J7.3; also elsewhere on the board
TV_OUT: J8.11
USB2_N: J8.3; also elsewhere on the board
USB2_P: J8.5; also elsewhere on the board
USBOTG_ID: J8.1; also elsewhere on the board
VCC1V8: J7.88, J7.90
WL_nDis: J7.89
nEXTRST: J7.100
nPWR_LED: J7.95

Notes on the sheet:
Raspberry CM4 connector

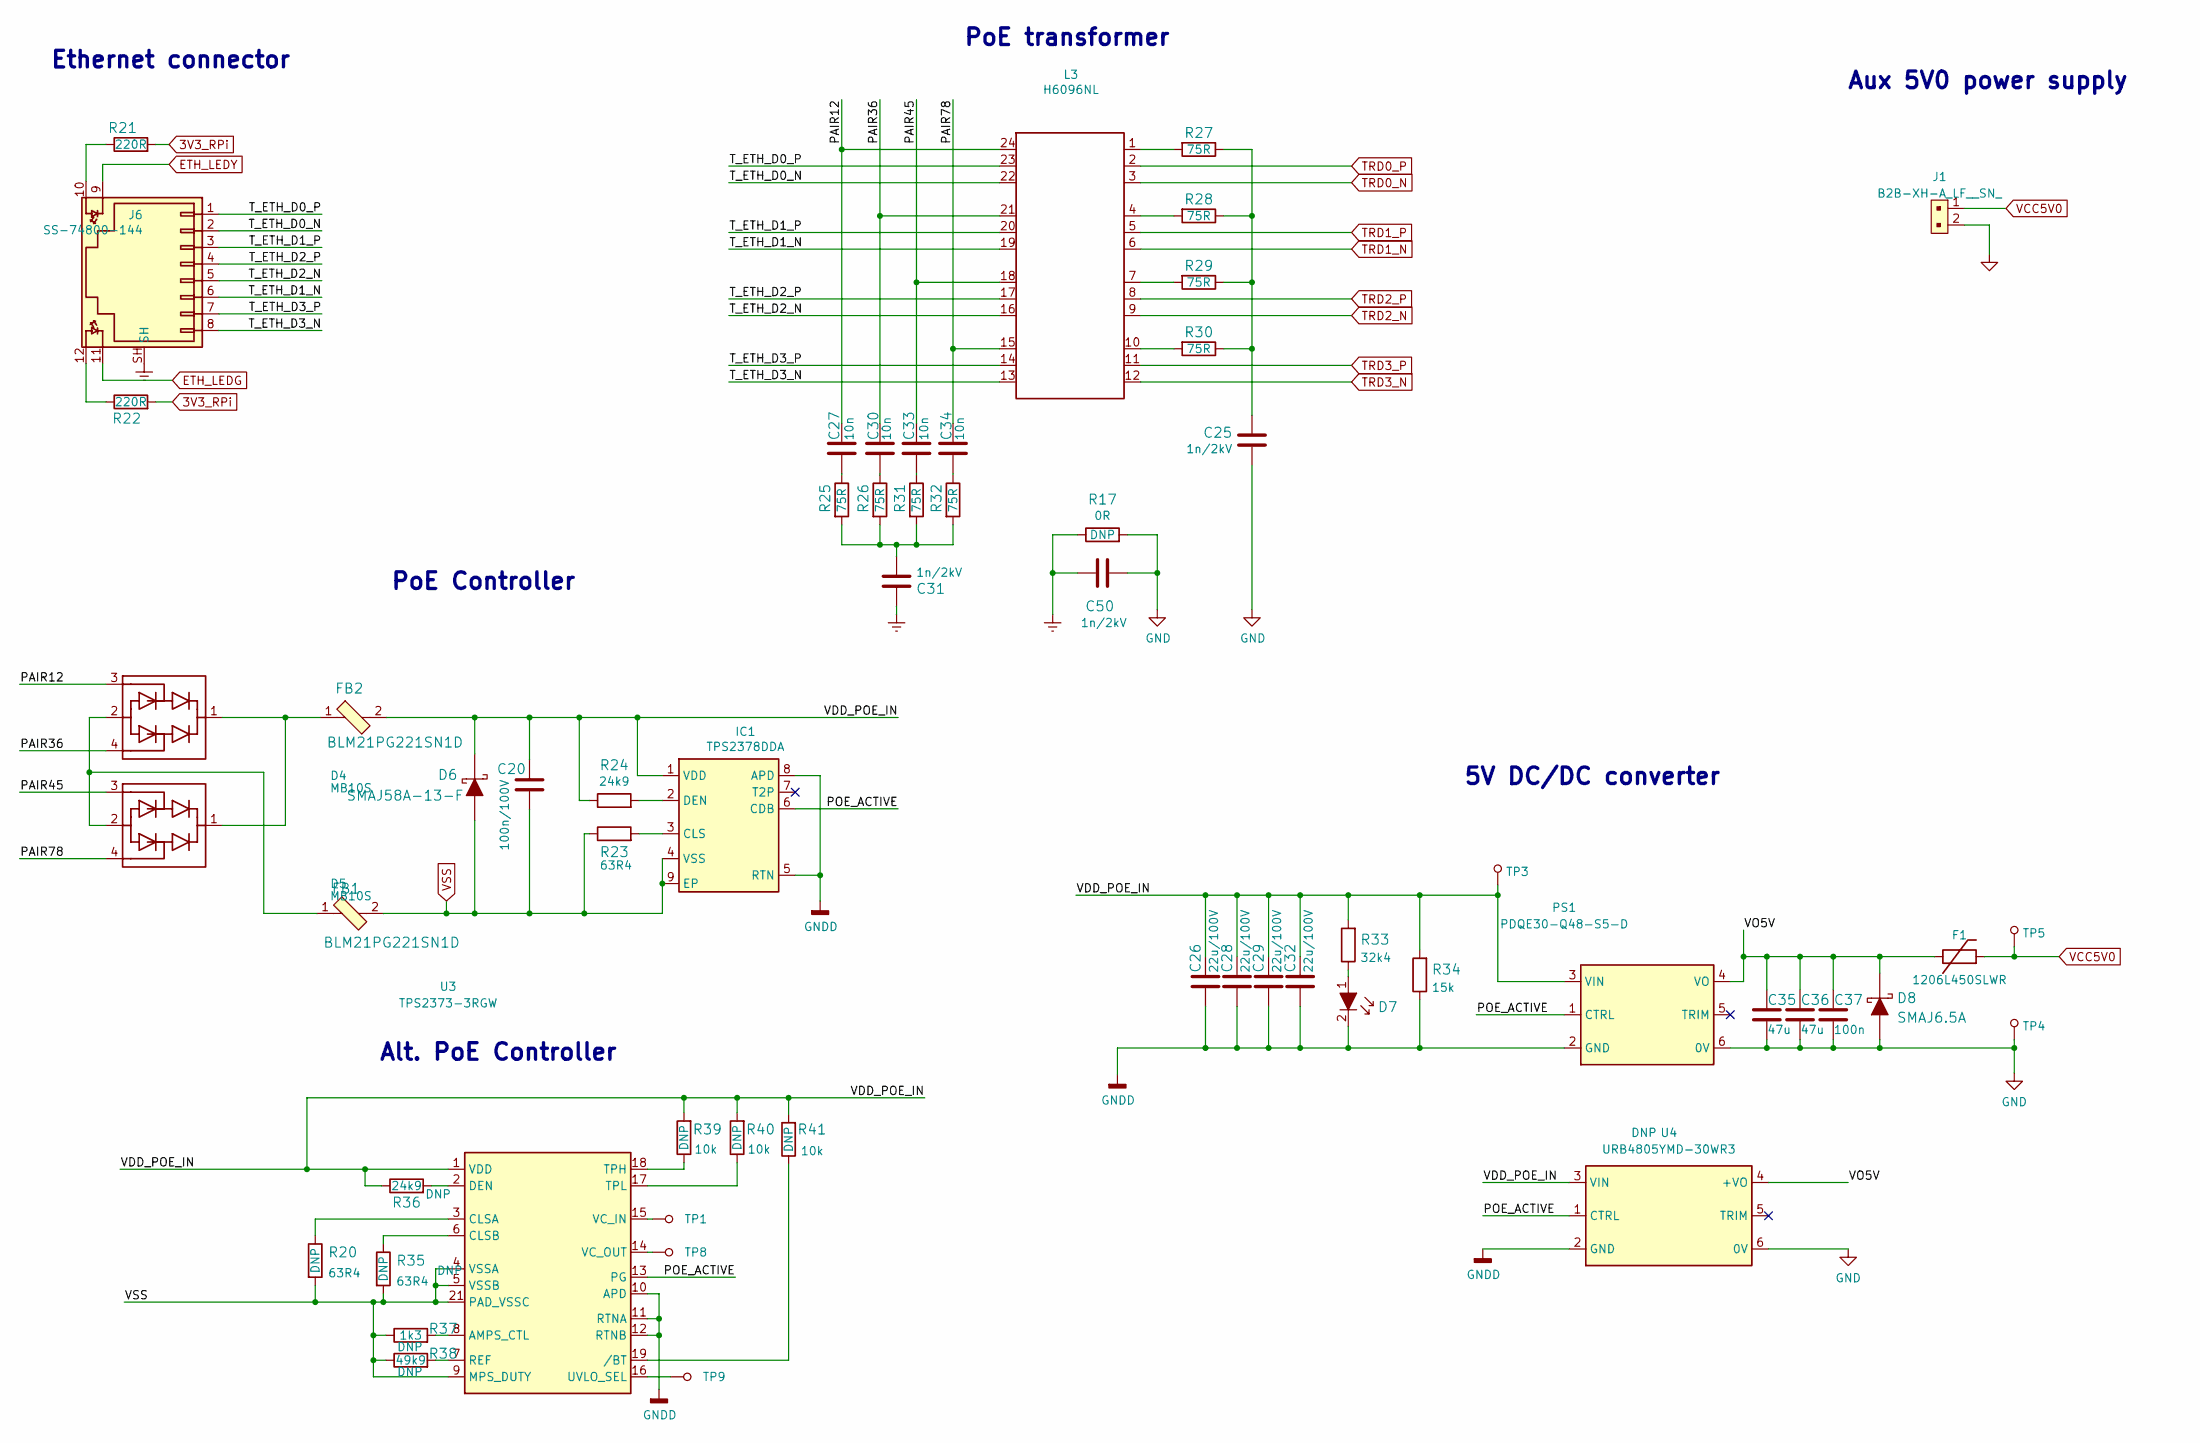
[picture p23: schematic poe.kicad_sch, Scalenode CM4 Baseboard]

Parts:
C20: C_100n_0805_100V; 0805-cap; MPN CL21B104KCFNNNE
C25, C31, C50: C_1n_1210_2kV; 1210-cap; MPN C1210C102KGRACTU
C26, C28, C29, C32: C_22u_2220_100V; 2220-cap; MPN C5750X7S2A226M280KB
C27, C30, C33, C34: C_10n_0402; 0402-cap; MPN 04025G103ZAT2A
C35, C36: C_47u_0603; 0603-cap; MPN GRM188R60J476ME15D
C37: C_100n_0402; 0402-cap; MPN 0402X104K6R3CT
D4, D5: MB10S; SOIC-4_4.2x5.0mm_P5.7mm; MPN MB10S
D6: SMAJ58A-13-F; DO-214AC; MPN SMAJ58A-13-F
D7: KP-1608CGCK; LED_0603; MPN KP-1608CGCK
D8: SMAJ6.5A; DO-214AC; MPN SMAJ6.5A
F1: 1206L450SLWR; 1206-res; MPN 1206L450SLWR
FB1, FB2: BLM21PG221SN1D; 0805-res; MPN BLM21PG221SN1D
IC1: TPS2378DDA; VQFN-20_5x5x1mm_P0.65mm; MPN TPS2378DDA; Mouser Part Number 595-TPS2378DDA
J1: B2B-XH-A_LF__SN_; PinHeader_1x2_P2.5mm_Drill1.1mm; MPN B2B-XH-A(LF)(SN)
J6: SS-74800-144; MPN SS-74800-144
L3: H6096NL; SOIC127P1594X685-24N; MPN H6096NL
PS1: PDQE30-Q48-S5-D; PDQE30-Q48; MPN PDQE30-Q48-S5-D
R17: R_0R_1206; 1206-res; MPN MCMR12X000_PTL
R20, R23, R35: R_63R4_0402; 0402-res; MPN CRCW040263R4FKED
R21, R22: R_220R_0402; 0402-res; MPN ERJ2GEJ221X
R24, R36: R_24k9_0402; 0402-res; MPN WR04X2492FTL
R25, R26, R27, R28, R29, R30, R31, R32: R_75R_0402; 0402-res; MPN RC0402FR-0775RL
R33: R_32k4_0805; 0805-res; MPN ERA-6AEB3242V
R34: R_15k_0603; 0603-res; MPN CR0603-FX-1502ELF
R37: R_1k3_0402; 0402-res; MPN CR0402-FX-1301GLF
R38: R_49k9_0402; 0402-res; MPN CRCW040249K9FKED
R39, R40, R41: R_10k_0402; 0402-res; MPN CRCW040210K0FKEDHP
TP1, TP8, TP9: TP_SMD_0_75MM; Testpoint_smd_0_75mm
TP3, TP4, TP5: TP_SMD1MM; Testpoint_smd_1mm
U3: TPS2373-3RGW; SOT-583; MPN TPS2373-3RGWR
U4: URB4805YMD-30WR3; MPN URB4805YMD-30WR3

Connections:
3V3_RPi: R21.2, R22.2; also elsewhere on the board
/PoE/PAIR12: C27.1, D4.3, L3.24 (MCT1)
/PoE/PAIR36: C30.1, D4.4, L3.21 (MCT2)
/PoE/PAIR45: C33.1, D5.3, L3.18 (MCT3)
/PoE/PAIR78: C34.1, D5.4, L3.15 (MCT4)
/PoE/POE_ACTIVE: IC1.6 (CDB), PS1.1 (CTRL), U3.13 (PG), U4.1 (CTRL)
/PoE/T_ETH_D0_N: J6.2, L3.22 (MX1-)
/PoE/T_ETH_D0_P: J6.1, L3.23 (MX1+)
/PoE/T_ETH_D1_N: J6.6, L3.19 (MX2-)
/PoE/T_ETH_D1_P: J6.3, L3.20 (MX2+)
/PoE/T_ETH_D2_N: J6.5, L3.16 (MX3-)
/PoE/T_ETH_D2_P: J6.4, L3.17 (MX3+)
/PoE/T_ETH_D3_N: J6.8, L3.13 (MX4-)
/PoE/T_ETH_D3_P: J6.7, L3.14 (MX4+)
/PoE/VDD_POE_IN: C20.1, C26.1, C28.1, C29.1, C32.1, D6.K, FB2.2, IC1.1 (VDD), PS1.3 (VIN), R24.1, R33.2, R34.2, R36.1, R39.2, R40.2, R41.2, TP3.1, U3.1 (VDD), U4.3 (VIN)
/PoE/VO5V: C35.1, C36.1, C37.1, D8.K, F1.1, PS1.4 (VO), U4.4 (+VO)
ETH_LEDG: J6.11; also elsewhere on the board
ETH_LEDY: J6.9; also elsewhere on the board
Earth: C31.2, C50.2, J6.SH, R17.1
GNDD: C26.2, C28.2, C29.2, C32.2, D7.2, IC1.5 (RTN), IC1.8 (APD), PS1.2 (GND), R34.1, U3.10 (APD), U3.11 (RTNA), U3.12 (RTNB), U4.2 (GND)
unnamed: C25.2, R27.1, R28.1, R29.1, R30.1
unnamed: C27.2, R25.1
unnamed: C30.2, R26.1
unnamed: C31.1, R25.2, R26.2, R31.2, R32.2
unnamed: C33.2, R31.1
unnamed: C34.2, R32.1
unnamed: D4.1, D5.1, FB2.1
unnamed: D4.2, D5.2, FB1.1
unnamed: D7.1, R33.1
unnamed: IC1.2 (DEN), R24.2
unnamed: J6.10, R21.1
unnamed: J6.12, R22.1
unnamed: L3.1 (TCT1), R27.2
unnamed: L3.4 (TCT2), R28.2
unnamed: L3.7 (TCT3), R29.2
unnamed: L3.10 (TCT4), R30.2
unnamed: R20.1, U3.3 (CLSA)
unnamed: R35.1, U3.6 (CLSB)
unnamed: R36.2, U3.2 (DEN)
unnamed: R37.2, U3.8 (AMPS_CTL)
unnamed: R38.2, U3.7 (REF)
unnamed: R39.1, U3.18 (TPH)
unnamed: R40.1, U3.17 (TPL)
unnamed: R41.1, U3.19 (/BT)
unnamed: TP1.1, U3.15 (VC_IN)
unnamed: TP8.1, U3.14 (VC_OUT)
unnamed: TP9.1, U3.16 (UVLO_SEL)
TRD0_N: L3.3 (TD1-); also elsewhere on the board
TRD0_P: L3.2 (TD1+); also elsewhere on the board
TRD1_N: L3.6 (TD2-); also elsewhere on the board
TRD1_P: L3.5 (TD2+); also elsewhere on the board
TRD2_N: L3.9 (TD3-); also elsewhere on the board
TRD2_P: L3.8 (TD3+); also elsewhere on the board
TRD3_N: L3.12 (TD4-); also elsewhere on the board
TRD3_P: L3.11 (TD4+); also elsewhere on the board

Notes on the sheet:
Alt. PoE Controller
Aux 5V0 power supply
PoE Controller
Ethernet connector
5V DC/DC converter
PoE transformer

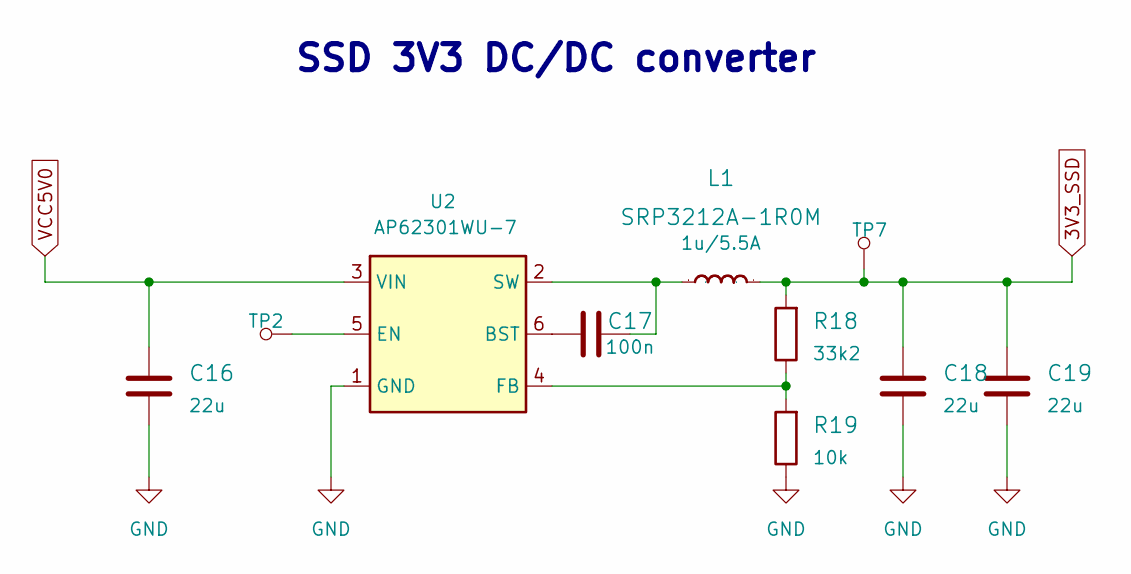
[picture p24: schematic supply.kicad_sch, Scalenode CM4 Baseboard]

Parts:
C16, C18, C19: C_22u_0805_10V; 0805-cap; MPN 0805ZD226MAT2A
C17: C_100n_0402; 0402-cap; MPN GRM155R61H104KE14D
L1: SRP3212A-1R0M; SRP3212; MPN SRP3212A-1R0M
R18: R_33k2_0402; 0402-res; MPN ERJ2RKF3322X
R19: R_10k_0402; 0402-res; MPN CRCW040210K0FKEDHP
TP2, TP7: TP_SMD1MM; Testpoint_smd_1mm
U2: AP62301WU-7; AP62301WU-7-TSOT23-6; MPN AP62301WU-7

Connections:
3V3_SSD: C18.1, C19.1, L1.2, R18.2, TP7.1; also elsewhere on the board
unnamed: C17.1, U2.6 (BST)
unnamed: C17.2, L1.1, U2.2 (SW)
unnamed: R18.1, R19.2, U2.4 (FB)
unnamed: TP2.1, U2.5 (EN)

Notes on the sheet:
SSD 3V3 DC/DC converter

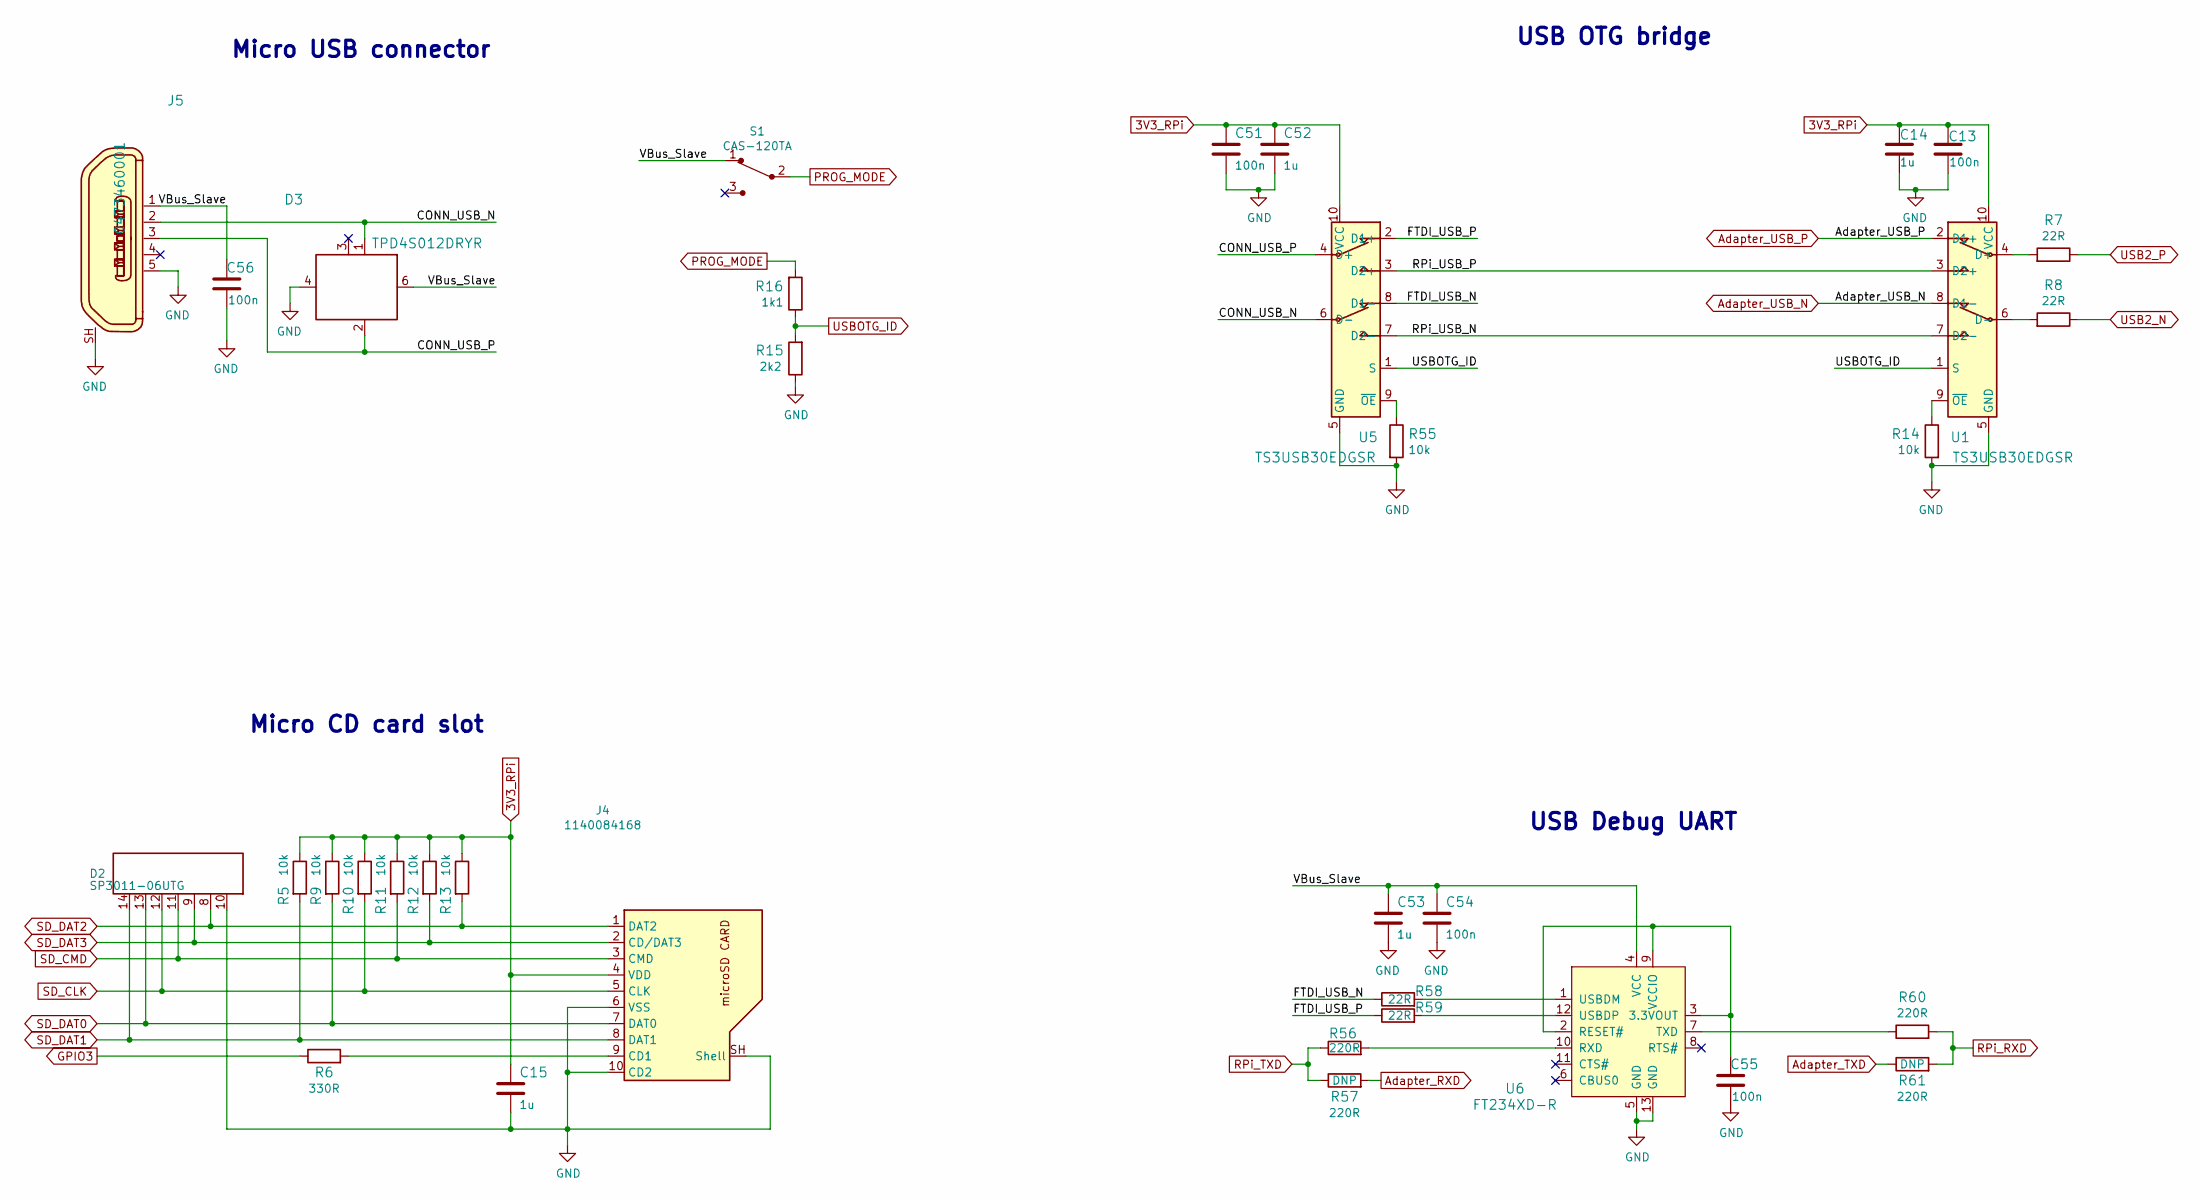
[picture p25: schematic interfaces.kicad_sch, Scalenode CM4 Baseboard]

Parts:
C13, C51, C54, C55, C56: C_100n_0402; 0402-cap; MPN 0402X104K6R3CT
C14, C15, C52, C53: C_1u_0402; 0402-cap; MPN C1005X6S1A105K050BC
D2: SP3011-06UTG; SON50P350X135X55-14N; MPN SP3011-06UTG
D3: TPD4S012DRYR; UFDFN-6_1.45x1mm; MPN TPD4S012DRYR
J4: 1140084168; MicroSD_Amphenol_1140084168; MPN 1140084168
J5: 0473460001; USB_Micro_B_Female_0473460001; MPN 0473460001
R5, R9, R10, R11, R12, R13, R14, R55: R_10k_0402; 0402-res; MPN CRCW040210K0FKEDHP
R6: R_330R_0402; 0402-res; MPN MCMR04X3300FTL
R7, R8, R58, R59: R_22R_0402; 0402-res; MPN CRCW040222R0FKED
R15: R_2k2_0402; 0402-res; MPN RC0402FR-072K2L
R16: R_1k1_0402; 0402-res; MPN ERJ2RKF1101X
R56, R57, R60, R61: R_220R_0402; 0402-res; MPN ERJ2GEJ221X
S1: CAS-120TA; Switch_Slide_CAS-120TA; MPN CAS-120TA
U1, U5: TS3USB30EDGSR; MSOP-10_W3mm; MPN TS3USB30EDGSR
U6: FT234XD-R; DFN-12-1EP_3x3mm; MPN FT234XD-R

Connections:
3V3_RPi: C13.1, C14.1, C15.1, C51.1, C52.1, J4.4 (VDD), R5.1, R9.1, R10.1, R11.1, R12.1, R13.1, U1.10 (VCC), U5.10 (VCC); also elsewhere on the board
/Interfaces/CONN_USB_N: D3.1 (D+), J5.2, U5.6 (D-)
/Interfaces/CONN_USB_P: D3.2 (D-), J5.3, U5.4 (D+)
/Interfaces/FTDI_USB_N: R58.1, U5.8 (D1-)
/Interfaces/FTDI_USB_P: R59.1, U5.2 (D1+)
/Interfaces/RPi_USB_N: U1.7 (D2-), U5.7 (D2-)
/Interfaces/RPi_USB_P: U1.3 (D2+), U5.3 (D2+)
/Interfaces/VBus_Slave: C53.1, C54.1, C56.1, D3.6 (VBUS), J5.1, S1.1, U6.4 (VCC)
Adapter_RXD: R57.2; also elsewhere on the board
Adapter_TXD: R61.1; also elsewhere on the board
Adapter_USB_N: U1.8 (D1-); also elsewhere on the board
Adapter_USB_P: U1.2 (D1+); also elsewhere on the board
GPIO3: R6.1; also elsewhere on the board
unnamed: C55.1, U6.2 (RESET#), U6.3 (3.3VOUT), U6.9 (VCCIO)
unnamed: J4.9 (CD1), R6.2
unnamed: R7.2, U1.4 (D+)
unnamed: R8.2, U1.6 (D-)
unnamed: R14.1, U1.9 (~OE)
unnamed: R55.1, U5.9 (~OE)
unnamed: R56.2, U6.10 (RXD)
unnamed: R58.2, U6.1 (USBDM)
unnamed: R59.2, U6.12 (USBDP)
unnamed: R60.1, U6.7 (TXD)
PROG_MODE: R16.2, S1.2; also elsewhere on the board
RPi_RXD: R60.2, R61.2; also elsewhere on the board
RPi_TXD: R56.1, R57.1; also elsewhere on the board
SD_CLK: D2.12 (D2+), J4.5 (CLK), R10.2; also elsewhere on the board
SD_CMD: D2.11 (D2-), J4.3 (CMD), R11.2; also elsewhere on the board
SD_DAT0: D2.13 (D1-), J4.7 (DAT0), R9.2; also elsewhere on the board
SD_DAT1: D2.14 (D1+), J4.8 (DAT1), R5.2; also elsewhere on the board
SD_DAT2: D2.8 (D3-), J4.1 (DAT2), R13.2; also elsewhere on the board
SD_DAT3: D2.9 (D3+), J4.2 (CD/DAT3), R12.2; also elsewhere on the board
USB2_N: R8.1; also elsewhere on the board
USB2_P: R7.1; also elsewhere on the board
USBOTG_ID: R15.2, R16.1, U1.1 (S), U5.1 (S); also elsewhere on the board

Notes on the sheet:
USB Debug UART
Micro USB connector
USB OTG bridge
Micro CD card slot

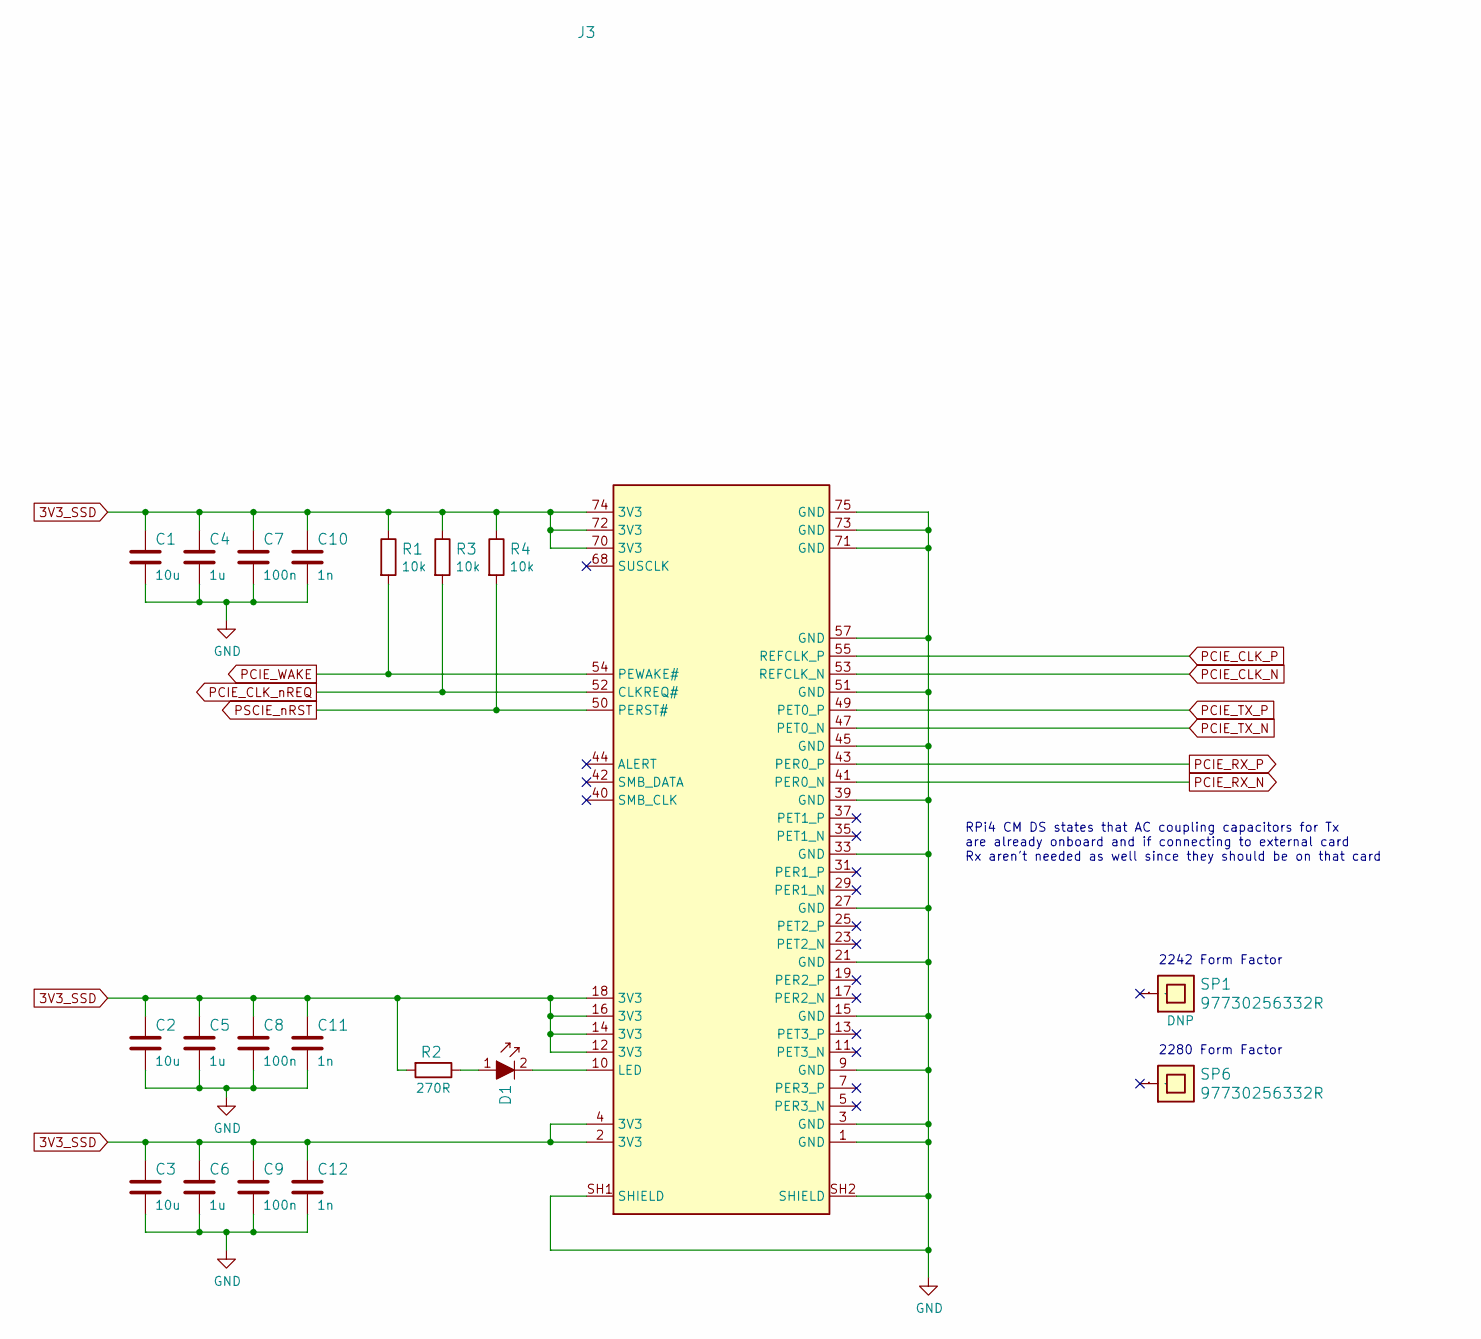
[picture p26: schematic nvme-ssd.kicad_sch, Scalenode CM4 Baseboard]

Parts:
C1, C2, C3: C_10u_0603; 0603-cap; MPN GRM188R61A106KE69D
C4, C5, C6: C_1u_0603; 0603-cap; MPN 0603YD105KAT2A
C7, C8, C9: C_100n_0603; 0603-cap; MPN 0603YC104KAZ2A
C10, C11, C12: C_1n_0603; 0603-cap; MPN 06031C102JAT2A
D1: 598-8D80-107F; LED_0603_R; MPN 598-8D80-107F
J3: 1-2199230-6; MPN 1-2199230-6
R1, R3, R4: R_10k_0603; 0603-res; MPN CR0603-JW-103ELF
R2: R_270R_0603; 0603-res; MPN CRGH0603F270R
SP1, SP6: 97730256332R; MPN 97730256332R

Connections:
3V3_SSD: C1.1, C2.1, C3.1, C4.1, C5.1, C6.1, C7.1, C8.1, C9.1, C10.1, C11.1, C12.1, J3.2 (3V3), J3.4 (3V3), J3.12 (3V3), J3.14 (3V3), J3.16 (3V3), J3.18 (3V3), J3.70 (3V3), J3.72 (3V3), J3.74 (3V3), R1.1, R2.2, R3.1, R4.1; also elsewhere on the board
unnamed: D1.1, R2.1
unnamed: D1.2, J3.10 (LED)
PCIE_CLK_N: J3.53 (REFCLK_N); also elsewhere on the board
PCIE_CLK_P: J3.55 (REFCLK_P); also elsewhere on the board
PCIE_CLK_nREQ: J3.52 (CLKREQ#), R3.2; also elsewhere on the board
PCIE_RX_N: J3.41 (PER0_N); also elsewhere on the board
PCIE_RX_P: J3.43 (PER0_P); also elsewhere on the board
PCIE_TX_N: J3.47 (PET0_N); also elsewhere on the board
PCIE_TX_P: J3.49 (PET0_P); also elsewhere on the board
PCIE_WAKE: J3.54 (PEWAKE#), R1.2
PSCIE_nRST: J3.50 (PERST#), R4.2; also elsewhere on the board

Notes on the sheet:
2242 Form Factor
RPi4 CM DS states that AC coupling capacitors for Tx are already onboard and if connecting to external card Rx aren't needed as well since they should be on that card
2280 Form Factor

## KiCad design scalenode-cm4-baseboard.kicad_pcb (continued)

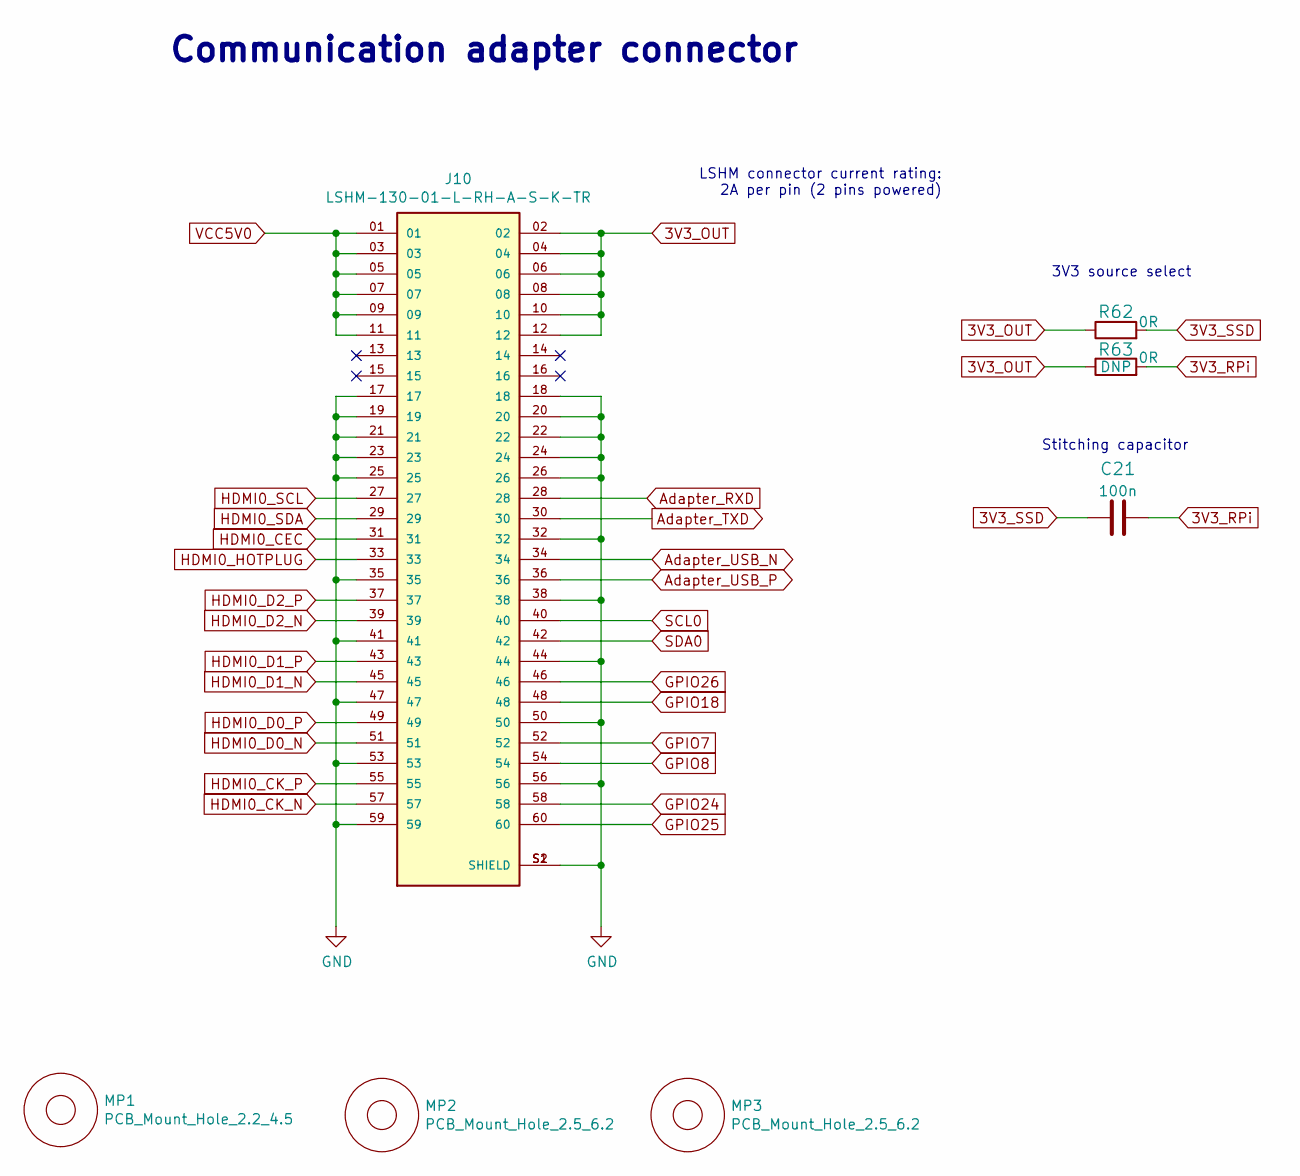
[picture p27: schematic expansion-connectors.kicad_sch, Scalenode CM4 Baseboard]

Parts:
C21: C_100n_0402; 0402-cap; MPN 0402X104K6R3CT
J10: LSHM-130-01-L-RH-A-S-K-TR; SAMTEC_LSHM-130-01-XXX-RH-A-S-K-XX; MPN LSHM-130-01-L-RH-A-S-K-TR
MP1: PCB_Mount_Hole_2.2_4.5; mounting-hole-2.2mm
MP2, MP3: PCB_Mount_Hole_2.5_6.2; Mount-hole-M2.5
R62, R63: R_0R_1206; 1206-res; MPN MCMR12X000_PTL

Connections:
3V3_OUT: J10.02, J10.04, J10.06, J10.08, J10.10, J10.12, R62.1, R63.1
3V3_RPi: C21.2, R63.2; also elsewhere on the board
3V3_SSD: C21.1, R62.2; also elsewhere on the board
Adapter_RXD: J10.28; also elsewhere on the board
Adapter_TXD: J10.30; also elsewhere on the board
Adapter_USB_N: J10.34; also elsewhere on the board
Adapter_USB_P: J10.36; also elsewhere on the board
GPIO7: J10.52; also elsewhere on the board
GPIO8: J10.54; also elsewhere on the board
GPIO18: J10.48; also elsewhere on the board
GPIO24: J10.58; also elsewhere on the board
GPIO25: J10.60; also elsewhere on the board
GPIO26: J10.46; also elsewhere on the board
HDMI0_CEC: J10.31; also elsewhere on the board
HDMI0_CK_N: J10.57; also elsewhere on the board
HDMI0_CK_P: J10.55; also elsewhere on the board
HDMI0_D0_N: J10.51; also elsewhere on the board
HDMI0_D0_P: J10.49; also elsewhere on the board
HDMI0_D1_N: J10.45; also elsewhere on the board
HDMI0_D1_P: J10.43; also elsewhere on the board
HDMI0_D2_N: J10.39; also elsewhere on the board
HDMI0_D2_P: J10.37; also elsewhere on the board
HDMI0_HOTPLUG: J10.33; also elsewhere on the board
HDMI0_SCL: J10.27; also elsewhere on the board
HDMI0_SDA: J10.29; also elsewhere on the board
SCL0: J10.40; also elsewhere on the board
SDA0: J10.42; also elsewhere on the board

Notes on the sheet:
LSHM connector current rating: 2A per pin (2 pins powered)
3V3 source select
Stitching capacitor
Communication adapter connector

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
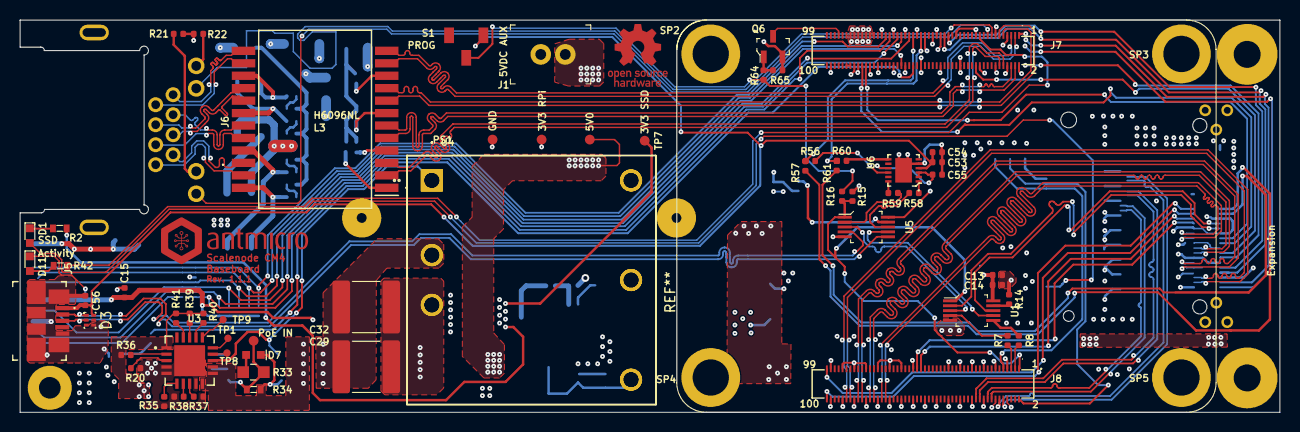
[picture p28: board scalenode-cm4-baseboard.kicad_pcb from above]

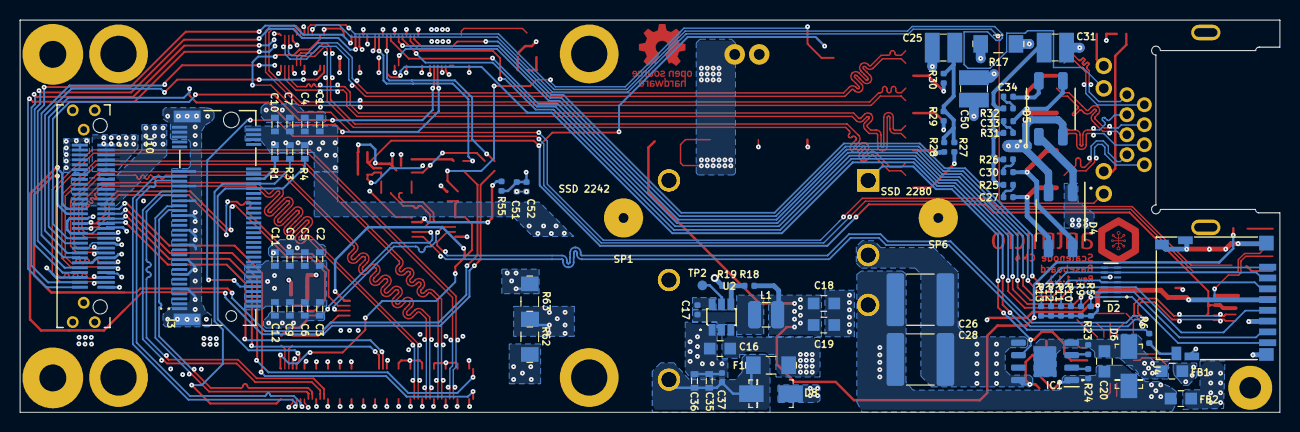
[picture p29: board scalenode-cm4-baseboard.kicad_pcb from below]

Board: 4 copper layers, 128.5 x 40.0 mm, 145 parts (74 on the bottom side), 135 nets.

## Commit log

2021-02-23 Add rev.1.0.0 design files
    [compute-module.sch, expansion-connectors.sch, interfaces.sch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]
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2021-02-23 Add PE in PoE coupling
    [compute-module.sch, poe.sch, scalenode.kicad_pcb]
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2021-02-23 Fix J7 J8 footprints
    [compute-module.sch, poe.sch, scalenode.kicad_pcb]
2021-02-23 Fix logotype
    [scalenode.kicad_pcb]
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2021-03-30 Connect GPIO_VREF signal to 3.3V_RPi
    [compute-module.sch, expansion-connectors.sch, interfaces.sch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]
2022-08-12 Migration to KiCad 6
    [compute-module.kicad_sch, compute-module.sch, expansion-connectors.kicad_sch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]
2022-08-12 Exchanged flyback to CUI DCDC converter on schematics. Added logos.
    [compute-module.kicad_sch, expansion-connectors.kicad_sch, interfaces.kicad_sch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]
2022-08-12 Added text fields with schematic descriptions
    [compute-module.kicad_sch, expansion-connectors.kicad_sch, interfaces.kicad_sch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]
2022-08-12 Implemented changes from rev 1.0.4. New components initial placement
    [compute-module.kicad_sch, expansion-connectors.kicad_sch, interfaces.kicad_sch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]
2022-08-12 Initial connection of all nets
    [scalenode.kicad_pcb]
2022-08-12 Shortened board. Adjusted posiitons of components. Routed all signals. Added stitching cap
    [expansion-connectors.kicad_sch, scalenode.kicad_pcb, scalenode.kicad_sch]
2022-08-12 Optimized routes. Added missing 3D models
    [interfaces.kicad_sch, scalenode.kicad_pcb]
2022-08-12 Corrected footprints. Adjusted position of testpoints. Cleared DRC
    [compute-module.kicad_sch, scalenode.kicad_pcb, scalenode.kicad_sch]
2022-08-12 Added stackup table and defined stackup in board settings
    [scalenode.kicad_pcb]
2022-08-12 Fixed and tuned differential pairs
    [scalenode.kicad_pcb]
2023-04-04 Corrected R33. Increased distance between L1 and L2. loclib
    [compute-module.kicad_sch, expansion-connectors.kicad_sch, interfaces.kicad_sch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]
2023-04-04 Added comment on MP2162 option
    [supply.kicad_sch]
2023-04-04 Changed 3V3 converter to AP62301WU-7
    [scalenode.kicad_pcb, scalenode.kicad_sch, supply.kicad_sch]
2023-04-04 Replaced 3.3V inductor with a smaller one to make m.2 fit
    [scalenode.kicad_pcb, scalenode.kicad_sch, supply.kicad_sch]
2023-04-04 Fixed silkscreen
    [scalenode.kicad_pcb]
2023-04-04 Added alternative PoE chip
    [poe.kicad_sch, scalenode.kicad_pcb, scalenode.kicad_sch]
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2023-04-04 Adjust logo, PCB name and rev to accomodate new project name
    [scalenode-cm4-baseboard.kicad_pcb]
2023-04-04 Bump revision to 1.1.1
    [compute-module.kicad_sch, expansion-connectors.kicad_sch, interfaces.kicad_sch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]
2023-04-04 Add URB4805YMD-30WR3 as DNP smps
    [expansion-connectors.kicad_sch, poe.kicad_sch, scalenode-cm4-baseboard.kicad_pcb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]
2023-04-04 Update PCB with DNP smps URB4805YMD-30WR3, review violations
    [compute-module.kicad_sch, expansion-connectors.kicad_sch, interfaces.kicad_sch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]
2023-04-04 Update PCB with corrected DF40HC(3.0)-100DS-0.4v footprint
    [scalenode-cm4-baseboard.kicad_pcb]
2023-04-04 Fix J7 and J8 designators size
    [scalenode-cm4-baseboard.kicad_pcb]
2023-05-11 Move ssd mounting points
    [scalenode-cm4-baseboard.kicad_pcb]
2023-05-11 Move u6,u5 and nearby passive components
    [scalenode-cm4-baseboard.kicad_pcb]
2023-05-11 Move ssd socket and filtering capacitors section
    [scalenode-cm4-baseboard.kicad_pcb]
2023-05-11 Move expansion adapter connector
    [scalenode-cm4-baseboard.kicad_pcb]
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2023-05-11 Connect and tuned diff pairs
    [scalenode-cm4-baseboard.kicad_pcb]
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2023-05-11 Move J10 0.8mm left
    [scalenode-cm4-baseboard.kicad_pcb]
2023-05-11 Tune difff pairs and Realocate zones
    [scalenode-cm4-baseboard.kicad_pcb]
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2023-05-11 Guide tracks out of vias
    [scalenode-cm4-baseboard.kicad_pcb]
2023-05-11 Move U5 to create more space for HDMI routing
    [scalenode-cm4-baseboard.kicad_pcb]
2023-05-11 Reroute high speed signals and GPIO signals
    [scalenode-cm4-baseboard.kicad_pcb]
2023-05-11 Tune high speed signals
    [scalenode-cm4-baseboard.kicad_pcb]
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2023-05-11 Add gnd plane next to PCIe vias
    [scalenode-cm4-baseboard.kicad_pcb]
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2023-05-11 Add stitching capacitors to high speed traces
    [scalenode-cm4-baseboard.kicad_pcb]
2023-05-11 Wip after 2nd review
    [scalenode-cm4-baseboard.kicad_pcb]
2023-05-11 Reroute PCIe traces and GND connections to expansion connector
    [scalenode-cm4-baseboard.kicad_pcb]
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2023-05-11 Relocate zones underneath differential pairs
    [scalenode-cm4-baseboard.kicad_pcb]
2023-05-11 Add vias around J10
    [scalenode-cm4-baseboard.kicad_pcb]
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2023-05-16 Update C13, C17, C21, C37, C51, C54, C55, C56 symbol and footprint
    [compute-module.kicad_sch, expansion-connectors.kicad_sch, interfaces.kicad_sch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]
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2023-05-16 Update C26, C28, C29, C32 symbol and footprint
    [poe.kicad_sch, scalenode-cm4-baseboard.kicad_sch]
2023-05-16 Update C27, C30, C33, C34 symbol and footprint
    [poe.kicad_sch, scalenode-cm4-baseboard.kicad_sch]
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2023-05-17 Update R5, R9, R10, R11, R12, R13, R14, R19, R55, R65 symbol and footprint
    [compute-module.kicad_sch, interfaces.kicad_sch, poe.kicad_sch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]
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2023-05-17 Update R7, R8, R58, R59 symbol and footprint
    [interfaces.kicad_sch, scalenode-cm4-baseboard.kicad_sch]
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2023-05-17 Update R21, R22, R56, R57, R60, R61 symbol and footprints
    [interfaces.kicad_sch, poe.kicad_sch, scalenode-cm4-baseboard.kicad_sch]
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2023-05-17 Update R25, R26, R27, R28, R29, R30, R31, R32 symbol and footprint
    [poe.kicad_sch, scalenode-cm4-baseboard.kicad_sch]
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2023-05-18 Update TP2, TP3, TP4, TP5, TP6, TP7 symbol and footprint
    [compute-module.kicad_sch, poe.kicad_sch, scalenode-cm4-baseboard.kicad_sch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]
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2023-05-18 Update SP2, SP3, SP4, SP5 symbol and footprint
    [compute-module.kicad_sch, scalenode-cm4-baseboard.kicad_sch]
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2023-05-19 Remove DRC errors and warnings
    [compute-module.kicad_sch, expansion-connectors.kicad_sch, interfaces.kicad_sch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]
2023-05-19 Fixed schematic errors
    [compute-module.kicad_sch, expansion-connectors.kicad_sch, interfaces.kicad_sch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]
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2023-06-02 Fix project - "Update PCB from schematic" button works
    [compute-module.kicad_sch]
2023-06-12 Fix clearance lower than 0.125mm
2023-06-12 Fix kicad_pro file
2023-06-12 Reduce edge clearance and min hole diameter
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2023-07-20 [#46875] Replace Bus_M.2-0.5P-1-2199230-6 symbol
    Replace Bus_M.2-0.5P-1-2199230-6 symbol with Bus_M.2_1-2199230-6
    [nvme-ssd.kicad_sch, scalenode-cm4-baseboard.kicad_sch]
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2023-07-20 [#46875] Add wire between pins 79 and 81 of J7
    [compute-module.kicad_sch]
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2023-07-20 [#46875] Update PCB and fix DRC errors
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2023-07-21 [#46875] Revert kmake loclib
    This reverts commit a23b923226223a7ebbdda1690aa69773ccaf4a95.
    [compute-module.kicad_sch, expansion-connectors.kicad_sch, interfaces.kicad_sch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]
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2023-08-10 Move C28 and C26, switch SSD connector footprint to Bus_M.2_MDT580M01001
    [nvme-ssd.kicad_sch, scalenode-cm4-baseboard.kicad_sch]
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2023-08-11 Fix SP1 and SP6 symbol values
    [nvme-ssd.kicad_sch, scalenode-cm4-baseboard.kicad_sch]
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2023-08-31 [#47798] Corrected CM4 3D model position in z axis
2023-08-31 [#47798] Corrected M2 module 3D model position in z axis
2023-08-31 [#47798] Fix designators on the silkscreen layer
2023-09-12 Update CM4 standoffs to standardized version
    Run loclib
    [compute-module.kicad_sch, expansion-connectors.kicad_sch, interfaces.kicad_sch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]
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2024-04-02 [#56969] Correct component references
    [compute-module.kicad_sch, expansion-connectors.kicad_sch, interfaces.kicad_sch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]

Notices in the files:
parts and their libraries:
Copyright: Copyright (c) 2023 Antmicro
